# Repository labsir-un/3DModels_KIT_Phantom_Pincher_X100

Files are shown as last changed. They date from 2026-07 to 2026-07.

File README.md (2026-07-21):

# 3DModels — KIT Phantom Pincher X100

Modelos 3D, documentación y archivos de diseño (Autodesk Inventor) del KIT Phantom Pincher X100, un kit de clasificación de objetos basado en el manipulador PhantomX Pincher.

## Ensamble

El ensamble completo (Autodesk Inventor) se encuentra en [`Kit/ensamblesKit/kitDetallado.iam`](Kit/ensamblesKit/kitDetallado.iam).

## Vista general del kit

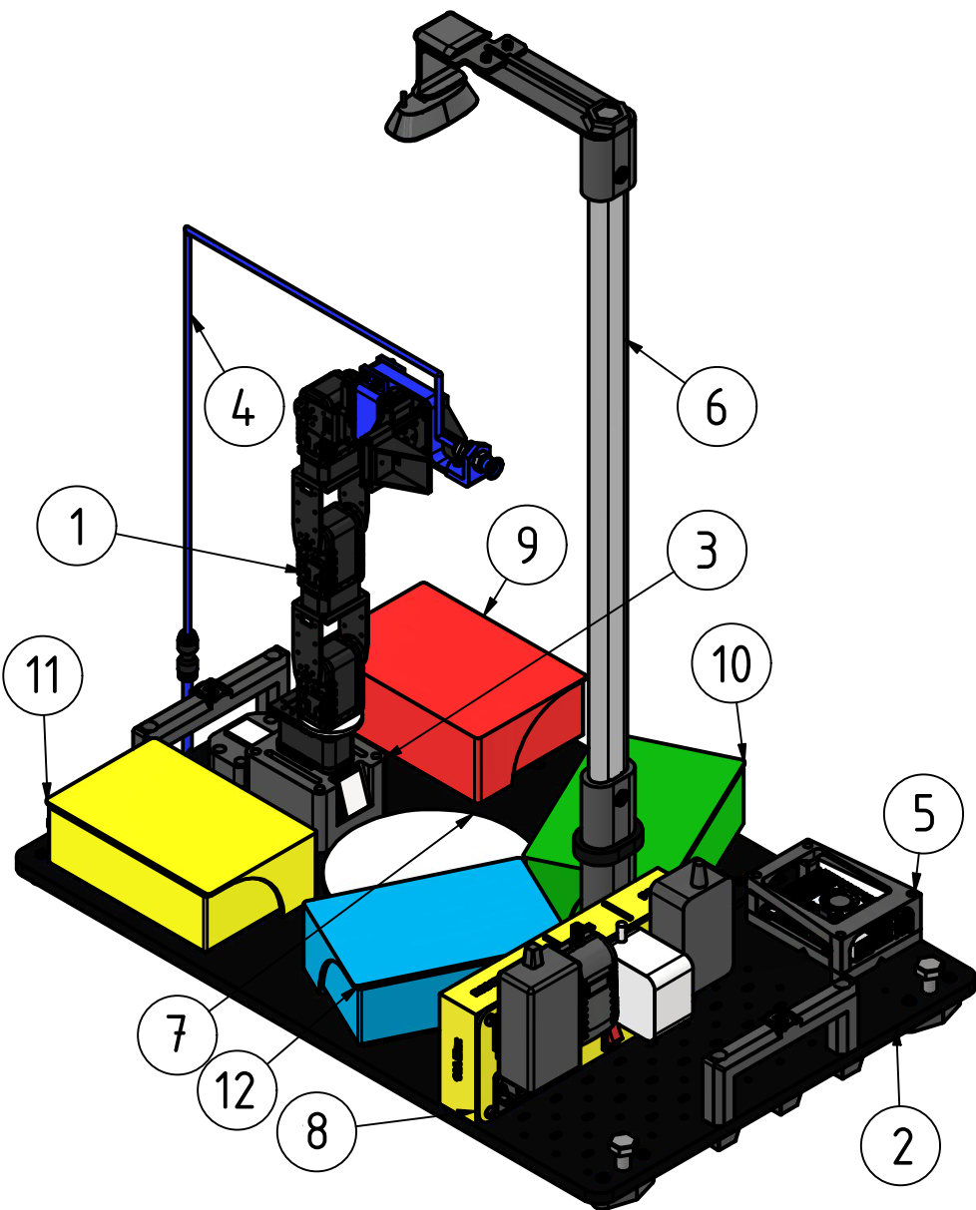
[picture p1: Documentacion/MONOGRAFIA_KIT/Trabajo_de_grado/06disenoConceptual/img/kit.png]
Vista general del kit


Kit de clasificación completo ensamblado. Sus partes son:

1. Manipulador robótico PhantomX Pincher AX-12 con 4 grados de libertad. Carpeta [`Kit/arm/`](Kit/arm), ver [`ensambleBrazo.iam`](Kit/arm/ensambleBrazo.iam).
2. Plataforma base de MDF (554 mm × 360 mm × 9 mm) con acabado negro mate. Carpeta [`Kit/basesParaLosKits/`](Kit/basesParaLosKits), ver [`ensambleBase.iam`](Kit/basesParaLosKits/ensambleBase.iam).
3. Base del manipulador con sistema de identificación numérica. Carpeta [`Kit/arm/`](Kit/arm), ver [`ensambleBaseBrazo.iam`](Kit/arm/ensambleBaseBrazo.iam).
4. Sistema de succión por vacío con gripper intercambiable. Carpeta [`Kit/cases/caseMicroAirPump370A/`](Kit/cases/caseMicroAirPump370A), ver [`ensambleAirpump.iam`](Kit/cases/caseMicroAirPump370A/ensambleAirpump.iam).
5. Controlador Raspberry Pi 5 en carcasa protectora. Carpeta [`Kit/cases/caseRaspberryPi5/turtleCasePi5/`](Kit/cases/caseRaspberryPi5/turtleCasePi5), ver [`raspberryPi5WithCase.iam`](Kit/cases/caseRaspberryPi5/turtleCasePi5/raspberryPi5WithCase.iam).
6. Soporte de cámara con mástil vertical y brazo en voladizo. Carpeta [`Kit/tubosOvaladosNiquel/soporteCamara/`](Kit/tubosOvaladosNiquel/soporteCamara), ver [`ensambleSoporteC270Webcam.iam`](Kit/tubosOvaladosNiquel/soporteCamara/ensambleSoporteC270Webcam.iam).
7. Zona de recolección circular blanca (Ø146 mm). Carpeta [`Kit/zonasDeRecolección/zonaCircular/`](Kit/zonasDeRecolecci%C3%B3n/zonaCircular), ver [`ensambleZonaRecoleccion.iam`](Kit/zonasDeRecolecci%C3%B3n/zonaCircular/ensambleZonaRecoleccion.iam).
8. Multitoma personalizada con control individual de subsistemas. Carpeta [`Kit/cases/multitoma/`](Kit/cases/multitoma), ver [`ensambleMultitoma.iam`](Kit/cases/multitoma/ensambleMultitoma.iam).
9. Caneca de depósito roja. Carpeta [`Kit/Canecas/canecaGrandeConTapaSlide/`](Kit/Canecas/canecaGrandeConTapaSlide), ver [`ensambleCanecaTapaSlide.iam`](Kit/Canecas/canecaGrandeConTapaSlide/ensambleCanecaTapaSlide.iam).
10. Caneca de depósito verde. Carpeta [`Kit/Canecas/canecaGrandeConTapaSlide/`](Kit/Canecas/canecaGrandeConTapaSlide), ver [`ensambleCanecaTapaSlide.iam`](Kit/Canecas/canecaGrandeConTapaSlide/ensambleCanecaTapaSlide.iam).
11. Caneca de depósito azul. Carpeta [`Kit/Canecas/canecaGrandeConTapaSlide/`](Kit/Canecas/canecaGrandeConTapaSlide), ver [`ensambleCanecaTapaSlide.iam`](Kit/Canecas/canecaGrandeConTapaSlide/ensambleCanecaTapaSlide.iam).
12. Caneca de depósito amarilla. Carpeta [`Kit/Canecas/canecaGrandeConTapaSlide/`](Kit/Canecas/canecaGrandeConTapaSlide), ver [`ensambleCanecaTapaSlide.iam`](Kit/Canecas/canecaGrandeConTapaSlide/ensambleCanecaTapaSlide.iam).

Todos los componentes se integran en un contenedor plástico de 600 mm × 400 mm para almacenamiento y transporte.

## Documentación del kit

Toda la información sobre el desarrollo del kit (imágenes del layout, partes, composición del robot, etc.) está en la carpeta [`Documentacion/MONOGRAFIA_KIT`](Documentacion/MONOGRAFIA_KIT). Allí encontrarás:

- [`Monografia_KIT.pdf`](Documentacion/MONOGRAFIA_KIT/Monografia_KIT.pdf): el documento final en PDF.
- [`Trabajo_de_grado/`](Documentacion/MONOGRAFIA_KIT/Trabajo_de_grado): el código fuente en LaTeX junto con las imágenes empleadas para generar el PDF.

## Layout del kit

Las imágenes del layout están en [`06disenoConceptual/img/plataforma/`](Documentacion/MONOGRAFIA_KIT/Trabajo_de_grado/06disenoConceptual/img/plataforma). La versión de referencia es [`layout2.png`](Documentacion/MONOGRAFIA_KIT/Trabajo_de_grado/06disenoConceptual/img/plataforma/layout2.png):

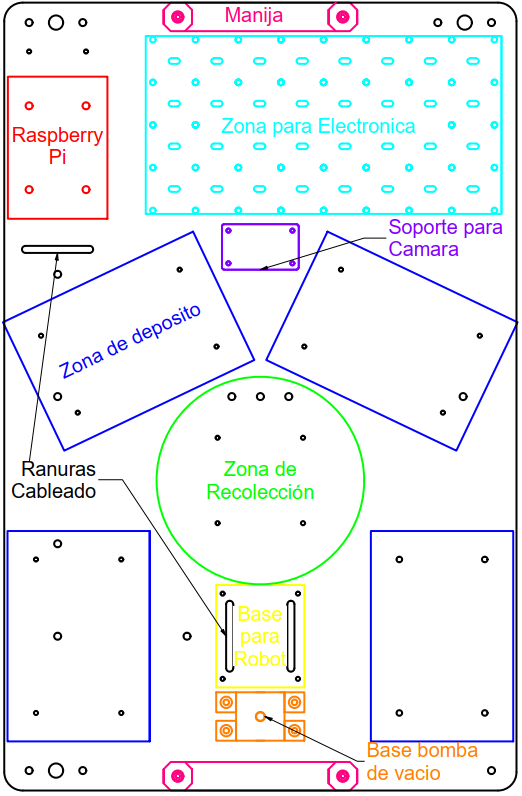
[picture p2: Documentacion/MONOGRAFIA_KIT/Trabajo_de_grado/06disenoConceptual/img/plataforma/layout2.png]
Layout del kit


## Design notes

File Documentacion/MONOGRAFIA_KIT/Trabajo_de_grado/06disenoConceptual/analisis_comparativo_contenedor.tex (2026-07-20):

\subsubsection{Análisis Comparativo de Alternativas}

Para determinar la opción más adecuada de contenedor, se realizó un análisis comparativo detallado considerando aspectos técnicos, económicos y operativos de ambas alternativas.

\paragraph{Especificaciones del Contenedor Comercial Seleccionado}

Se identificó en el mercado nacional una canastilla plástica industrial con las siguientes características:

\begin{itemize}
    \item \textbf{Tipo}: Canastilla plástica 3/4 toda sellada de fábrica
    \item \textbf{Material}: Polipropileno industrial
    \item \textbf{Incluye}: Tapa
    \item \textbf{Capacidad de carga}: 200 kg
    \item \textbf{Costo unitario}: \$25,000 COP
    \item \textbf{Estado}: Nuevo, sellado de fábrica
\end{itemize}

Esta solución comercial fue comparada con la alternativa de fabricación propia mediante un análisis multicriterio.

\paragraph{Análisis de Costos}

La Tabla \ref{tab:costos_contenedor} presenta una comparación detallada de los costos asociados a cada alternativa para la fabricación de los 7 contenedores requeridos.

\begin{table}[H]
\centering
\caption{Comparación de costos entre alternativas de contenedor}
\label{tab:costos_contenedor}
\begin{tabular}{|l|r|r|}
\hline
\textbf{Concepto} & \textbf{Fabricación Propia} & \textbf{Contenedor Comercial} \\
\hline
\hline
\multicolumn{3}{|l|}{\textit{Materiales}} \\
\hline
Madera/MDF (láminas) & \$280,000 & --- \\
Herrajes y bisagras & \$105,000 & --- \\
Asas de transporte & \$42,000 & Incluidas \\
Tornillería & \$21,000 & --- \\
Adhesivos y sellantes & \$35,000 & --- \\
Pintura y acabados & \$70,000 & --- \\
Canastillas plásticas (7 unidades) & --- & \$175,000 \\
\hline
\textbf{Subtotal materiales} & \$553,000 & \$175,000 \\
\hline
\hline
\multicolumn{3}{|l|}{\textit{Procesos y mano de obra}} \\
\hline
Corte de materiales & \$140,000 & --- \\
Ensamblaje & \$210,000 & --- \\
Acabado superficial & \$105,000 & --- \\
\hline
\textbf{Subtotal procesos} & \$455,000 & \$0 \\
\hline
\hline
\multicolumn{3}{|l|}{\textit{Herramientas y equipos}} \\
\hline
Arriendo/depreciación herramientas & \$84,000 & --- \\
\hline
\textbf{Subtotal herramientas} & \$84,000 & \$0 \\
\hline
\hline
\textbf{COSTO TOTAL (7 unidades)} & \$1,092,000 & \$175,000 \\
\textbf{Costo unitario} & \$156,000 & \$25,000 \\
\hline
\end{tabular}
\end{table}

El análisis de costos revela una diferencia significativa de \$917,000 COP a favor de la opción comercial, lo que representa un ahorro del 84\% respecto a la fabricación propia.

\paragraph{Análisis de Tiempos}

La Tabla \ref{tab:tiempos_contenedor} compara los tiempos de implementación requeridos para cada alternativa.

\begin{table}[H]
\centering
\caption{Comparación de tiempos de implementación}
\label{tab:tiempos_contenedor}
\begin{tabular}{|l|r|r|}
\hline
\textbf{Actividad} & \textbf{Fabricación Propia} & \textbf{Contenedor Comercial} \\
\hline
Diseño detallado & 16 horas & 0 horas \\
Adquisición de materiales & 8 horas & 2 horas \\
Fabricación/corte & 24 horas & --- \\
Ensamblaje & 28 horas & --- \\
Acabados & 16 horas & --- \\
Curado y secado & 48 horas & --- \\
Inspección y ajustes & 8 horas & 1 hora \\
\hline
\textbf{TOTAL} & \textbf{148 horas} & \textbf{3 horas} \\
\textbf{Días laborales (8h/día)} & \textbf{18.5 días} & \textbf{0.4 días} \\
\hline
\end{tabular}
\end{table}

La opción comercial representa un ahorro de 145 horas de trabajo, equivalente a aproximadamente 18 días laborales, permitiendo dedicar este tiempo a otras actividades críticas del proyecto.

\paragraph{Análisis Técnico Comparativo}

La Tabla \ref{tab:comparativo_tecnico} presenta una evaluación de los aspectos técnicos y funcionales de ambas alternativas.

\begin{table}[H]
\centering
\caption{Análisis técnico comparativo de alternativas de contenedor}
\label{tab:comparativo_tecnico}
\small
\begin{tabular}{|p{4cm}|p{5cm}|p{5cm}|}
\hline
\textbf{Criterio} & \textbf{Fabricación Propia} & \textbf{Contenedor Comercial} \\
\hline
\hline
\textbf{Capacidad de carga} & 150-180 kg (estimado, requiere refuerzos) & 200 kg (certificado) \\
\hline
\textbf{Resistencia a apilamiento} & Variable, depende de la construcción & Certificada para apilamiento industrial \\
\hline
\textbf{Resistencia a humedad} & Requiere sellado y mantenimiento periódico & Resistente, material impermeable \\
\hline
\textbf{Durabilidad} & 3-5 años con mantenimiento & 10+ años, sin mantenimiento \\
\hline
\textbf{Peso del contenedor} & 8-12 kg (madera/MDF) & 3-4 kg (plástico) \\
\hline
\textbf{Transportabilidad} & Limitada por peso y volumen & Excelente, liviano con asas integradas \\
\hline
\textbf{Estandarización} & Cada unidad puede variar ligeramente & Todas las unidades idénticas \\
\hline
\textbf{Mantenimiento} & Requiere repintado, ajuste de herrajes & Mínimo, solo limpieza \\
\hline
\textbf{Reemplazo} & Difícil, requiere fabricación nueva & Inmediato, disponible en mercado \\
\hline
\textbf{Personalización} & Alta, diseño completamente adaptable & Limitada a dimensiones estándar \\
\hline
\textbf{Estética} & Profesional con buen acabado & Industrial, funcional \\
\hline
\end{tabular}
\end{table}

\paragraph{Matriz de Decisión}

Para la selección final se empleó una matriz de decisión multicriterio ponderada (Tabla \ref{tab:matriz_decision}), asignando pesos a cada criterio según su importancia relativa en el contexto del proyecto.

\begin{table}[H]
\centering
\caption{Matriz de decisión multicriterio para selección de contenedor}
\label{tab:matriz_decision}
\begin{tabular}{|l|c|c|c|c|c|}
\hline
\textbf{Criterio} & \textbf{Peso} & \multicolumn{2}{c|}{\textbf{Fabricación Propia}} & \multicolumn{2}{c|}{\textbf{Contenedor Comercial}} \\
\cline{3-6}
 & (\%) & Calif. & Pond. & Calif. & Pond. \\
\hline
Costo & 25 & 4 & 1.00 & 10 & 2.50 \\
Tiempo de implementación & 20 & 3 & 0.60 & 10 & 2.00 \\
Capacidad de carga & 15 & 7 & 1.05 & 9 & 1.35 \\
Durabilidad & 15 & 6 & 0.90 & 9 & 1.35 \\
Facilidad de transporte & 10 & 5 & 0.50 & 9 & 0.90 \\
Disponibilidad & 10 & 4 & 0.40 & 10 & 1.00 \\
Mantenimiento & 5 & 5 & 0.25 & 10 & 0.50 \\
\hline
\textbf{TOTAL} & \textbf{100} & --- & \textbf{4.70} & --- & \textbf{9.60} \\
\hline
\end{tabular}
\end{table}

\textit{Nota: Calificación en escala de 1 a 10, donde 10 es el mejor desempeño.}

\paragraph{Conclusión del Análisis}

El análisis comparativo multicriterio demostró que la opción de contenedor comercial (canastilla plástica industrial) es significativamente superior a la fabricación propia, obteniendo una puntuación ponderada de 9.60 frente a 4.70.

Las ventajas decisivas del contenedor comercial son:

\begin{enumerate}
    \item \textbf{Ventaja económica}: Ahorro de \$917,000 COP (84\%) en el costo total de los 7 contenedores
    \item \textbf{Ventaja temporal}: Reducción de 18 días laborales en el tiempo de implementación
    \item \textbf{Ventaja técnica}: Capacidad de carga certificada de 200 kg, superior a la estimada para fabricación propia
    \item \textbf{Ventaja operativa}: Menor peso (3-4 kg vs 8-12 kg), facilitando el transporte manual
    \item \textbf{Ventaja de mantenimiento}: Material resistente a humedad sin requerimiento de mantenimiento periódico
    \item \textbf{Ventaja de disponibilidad}: Reemplazo inmediato en caso de daño o necesidad de unidades adicionales
\end{enumerate}

La única ventaja de la fabricación propia sería la personalización completa del diseño; sin embargo, esta ventaja no compensa las múltiples desventajas en costo, tiempo, y características técnicas.

Por estas razones, se seleccionó la canastilla plástica industrial como contenedor definitivo para los 7 kits del proyecto, permitiendo una implementación más rápida, económica y técnicamente superior, liberando recursos financieros y temporales que pueden ser destinados a otros componentes críticos del kit de clasificación.

    \begin{figure}[H]
        \centering
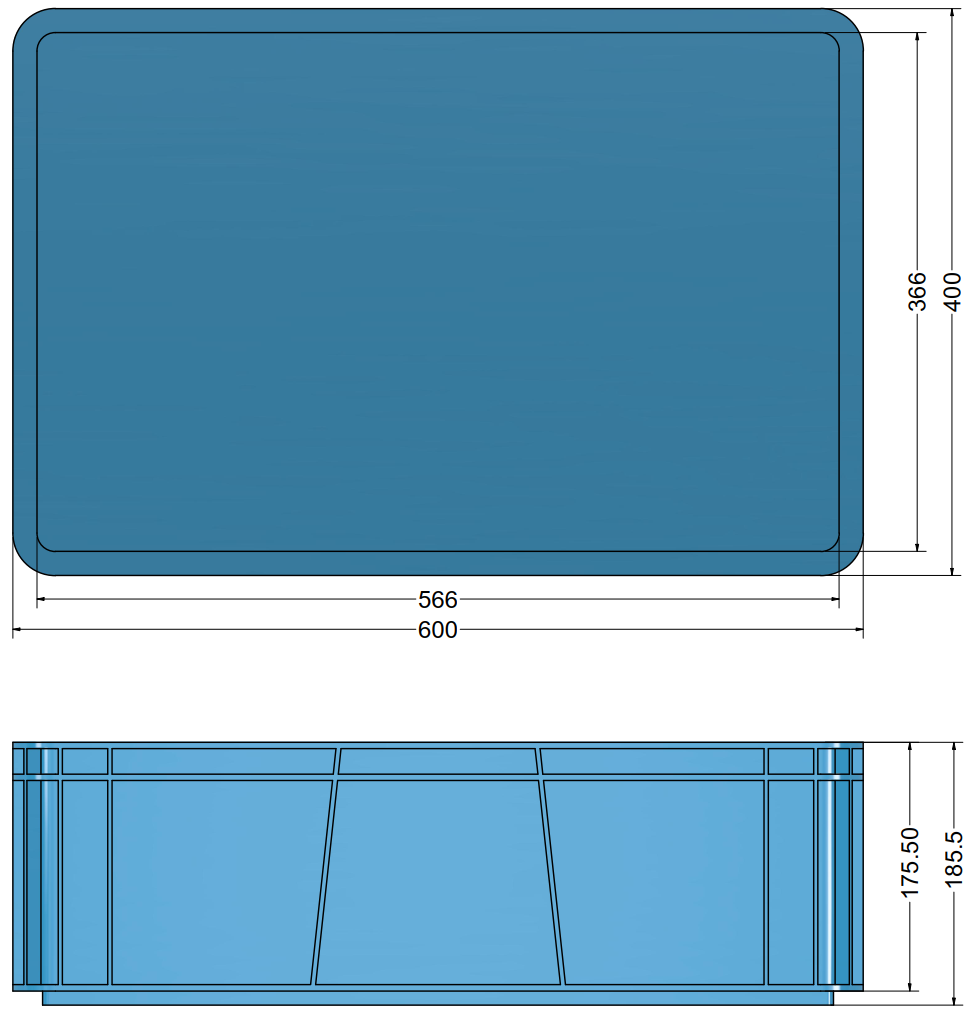
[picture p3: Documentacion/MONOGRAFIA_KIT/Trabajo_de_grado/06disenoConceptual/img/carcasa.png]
        
        \caption{Vista superior y lateral de canastilla 3/4 sellada con dimensiones externas e internas.}
        \label{fig:carcasa}
    \end{figure}

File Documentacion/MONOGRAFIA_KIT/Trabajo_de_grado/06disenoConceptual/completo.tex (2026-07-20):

\section{Kit de Clasificación Completo}

La integración de todos los subsistemas diseñados (mecánico, neumático, de control, de visión y eléctrico) resulta en un kit educativo compacto y funcional para enseñanza de robótica, visión por computador y ROS2. La Figura \ref{fig:kitCompleto} presenta el ensamblaje completo del kit con todos sus componentes principales.

\begin{figure}[H]
    \centering
    
    \caption{Kit de clasificación completo ensamblado. (1) Manipulador robótico PhantomX Pincher AX-12 con 4 grados de libertad, (2) Plataforma base de MDF (554 mm × 360 mm × 9 mm) con acabado negro mate, (3) Base del manipulador con sistema de identificación numérica, (4) Sistema de succión por vacío con gripper intercambiable, (5) Controlador Raspberry Pi 5 en carcasa protectora, (6) Soporte de cámara con mástil vertical y brazo en voladizo, (7) Zona de recolección circular blanca (Ø146 mm), (8) Multitoma personalizada con control individual de subsistemas, (9) Caneca de depósito roja, (10) Caneca de depósito verde, (11) Caneca de depósito azul, (12) Caneca de depósito amarilla. Todos los componentes se integran en contenedor plástico de 600 mm × 400 mm para almacenamiento y transporte.}
    \label{fig:kitCompleto}
\end{figure}

\subsection{Componentes Principales del Kit}

El kit integrado está compuesto por los siguientes subsistemas y componentes principales:

\begin{table}[H]
\centering
\caption{Componentes principales del kit de clasificación}
\label{tab:componentes_kit}
\small
\begin{tabular}{|c|l|}
\hline
\textbf{\#} & \textbf{Componente/Subsistema} \\
\hline
1 & Manipulador PhantomX Pincher AX-12 \\
2 & Plataforma base \\
3 & Base de manipulador \\
4 & Sistema de succión por vacío \\
5 & Controlador (Raspberry Pi 5) \\
6 & Soporte de cámara \\
7 & Zona de recolección \\
8 & Multitoma personalizada \\
9 & Caneca de depósito roja \\
10 & Caneca de depósito verde \\
11 & Caneca de depósito azul \\
12 & Caneca de depósito amarilla \\
\hline
\end{tabular}
\end{table}

\subsection{Características Generales del Kit}

El kit completo presenta las siguientes características técnicas y operativas:

\subsubsection{Dimensiones y Peso}

\begin{itemize}
    \item \textbf{Plataforma operativa}: 554 mm × 360 mm × 706 mm (largo × ancho × alto máximo con soporte de cámara)
    \item \textbf{Contenedor de almacenamiento}: 600 mm × 400 mm × 171 mm (exteriores)
    \item \textbf{Peso total estimado}: 4.5-5.5 kg (incluye todos los componentes y objetos de clasificación)
    \item \textbf{Portabilidad}: Transporte manual mediante asas integradas en contenedor
\end{itemize}

\subsubsection{Capacidades Funcionales}

\begin{itemize}
    \item \textbf{Espacio de trabajo}: Zona de recolección de Ø146 mm más cuatro zonas de depósito
    \item \textbf{Capacidad de manipulación}: Objetos de 25 mm × 25 mm × 25 mm, peso máximo 30 g
    \item \textbf{Tipos de objetos}: 4 geometrías distinguibles (cuadrado, rectángulo, círculo, pentágono)
    \item \textbf{Modos de operación}: Gripper mecánico o sistema de succión por vacío (intercambiables)
    \item \textbf{Clasificación por color}: 4 categorías (rojo, verde, azul, amarillo)
\end{itemize}

\subsubsection{Subsistemas Integrados}

\begin{itemize}
    \item \textbf{Subsistema mecánico}: Manipulador de 4 DOF, plataforma estructural, zonas de trabajo
    \item \textbf{Subsistema neumático}: Bomba de vacío 370A, ventosa PAK-15, mangueras de 4-6 mm
    \item \textbf{Subsistema de control}: Raspberry Pi 5 (8 GB RAM), Ubuntu 24.04 LTS, ROS2 Jazzy
    \item \textbf{Subsistema de visión}: Cámara Logitech C270, soporte ajustable en altura
    \item \textbf{Subsistema eléctrico}: Multitoma con 4 salidas, 3 switches individuales, protección por fusible 15A
\end{itemize}

\subsubsection{Recursos Didácticos}

El kit proporciona plataforma para práctica de:

\begin{itemize}
    \item Cinemática directa e inversa de manipuladores seriales
    \item Control de servomotores Dynamixel mediante protocolos de comunicación
    \item Visión por computador (segmentación de color, detección de formas, calibración de cámara)
    \item Programación de nodos ROS2 en Python/C++
    \item Planificación de trayectorias y evasión de colisiones
    \item Integración de sensores y actuadores en sistemas robóticos
    \item Desarrollo de interfaces de usuario para control de robots
\end{itemize}

\subsection{Configuración de Almacenamiento}

Todos los componentes del kit se almacenan en el contenedor plástico sellado mediante la siguiente distribución:

\begin{itemize}
    \item \textbf{Nivel inferior}: Plataforma base con canecas, zona de recolección, multitoma y base de manipulador fijos
    \item \textbf{Nivel medio}: Manipulador desmontado, carcasa de Raspberry Pi, bomba de vacío
    \item \textbf{Nivel superior}: Mástil de soporte de cámara (diagonal), gripper de succión, objetos de clasificación, cableado
    \item \textbf{Compartimentos laterales}: Fuentes de alimentación, cable de poder, mangueras neumáticas
\end{itemize}

Las tapas deslizantes de las canecas se cierran durante almacenamiento, conteniendo objetos de clasificación y previendo su pérdida durante transporte.

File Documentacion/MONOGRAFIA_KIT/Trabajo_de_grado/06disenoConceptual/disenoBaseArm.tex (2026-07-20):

\subsection{Diseño de la Base del Manipulador}

La base del manipulador constituye la interfaz mecánica entre el robot PhantomX Pincher y la plataforma del kit. Su diseño se fundamentó en la preservación de características funcionales de la base original, incorporando mejoras estructurales y adaptaciones específicas para el nuevo sistema.

\subsubsection{Análisis de la Base Original}

La base original del robot PhantomX Pincher AX-12 (Figura \ref{fig:ensambleOldBaseArm}) sirvió como referencia para el diseño, proporcionando información valiosa sobre dimensiones, sistemas de fijación y requisitos operativos.

\begin{figure}[H]
    \centering
    
    \caption{Base original del robot PhantomX Pincher AX-12. (1) Base superior de acrílico que soporta el servomotor principal, (2) Base inferior de acrílico para fijación a superficies, (3) Cuatro espaciadores hexagonales de nylon M3, (4) Manipulador PhantomX Pincher. Se observan las ranuras laterales para paso de cableado.}
    \label{fig:ensambleOldBaseArm}
\end{figure}

\begin{table}[H]
\centering
\caption{Componentes de la base original del PhantomX Pincher AX-12}
\label{tab:base_original}
\small
\begin{tabular}{|c|l|c|l|}
\hline
\textbf{\#} & \textbf{Componente} & \textbf{Cant.} & \textbf{Material} \\
\hline
1 & Base superior de manipulador & 1 & Acrílico \\
2 & Base inferior de manipulador & 1 & Acrílico \\
3 & Espaciador hexagonal de nylon M3 & 4 & Nylon \\
4 & Manipulador & 1 & --- \\
\hline
\end{tabular}
\end{table}

La altura de la base original es de 48 mm (Figura \ref{fig:medidaBaseArmOld}), dimensión que se conservó en el diseño final para mantener la compatibilidad cinemática con los algoritmos de control existentes.

\begin{figure}[H]
    \centering
    
    \caption{Vista lateral de la base original mostrando la altura total de 48 mm desde la superficie de montaje hasta la interfaz del manipulador.}
    \label{fig:medidaBaseArmOld}
\end{figure}

\subsubsection{Características Preservadas del Diseño Original}

Del diseño original se conservaron los siguientes elementos funcionales:

\begin{itemize}
    \item \textbf{Sistema de espaciadores hexagonales}: Se mantiene el uso de cuatro espaciadores M3 para fijación del manipulador, garantizando compatibilidad mecánica
    \item \textbf{Ranuras laterales de cableado}: Se preservan las dos aberturas laterales que permiten el paso de cables desde la zona de electrónica hasta el manipulador
    \item \textbf{Altura estándar}: Se conserva la altura de 48 mm para mantener la compatibilidad con la cinemática del robot
\end{itemize}

\subsubsection{Modificaciones e Innovaciones del Diseño}

El diseño final incorpora mejoras significativas respecto a la base original:

\paragraph{Eliminación de la Base Inferior}

Se suprimió la placa inferior de la base original, ya que la plataforma del kit cumple esta función. Esta simplificación reduce:
\begin{itemize}
    \item Número de componentes del sistema
    \item Costo de fabricación
    \item Peso total del conjunto
    \item Complejidad de ensamblaje
\end{itemize}

\paragraph{Integración con Sistema de Vacío}

Se diseñó una cavidad semicircular en la parte posterior de la base (visible en la Figura \ref{fig:medidasBaseArm}) para alojar la bomba de vacío. Esta integración permite:
\begin{itemize}
    \item Aprovechamiento óptimo del espacio disponible
    \item Proximidad entre bomba de vacío y manipulador, minimizando longitud de mangueras
    \item Protección parcial de la bomba dentro del volumen de la base
\end{itemize}

\begin{figure}[H]
    \centering
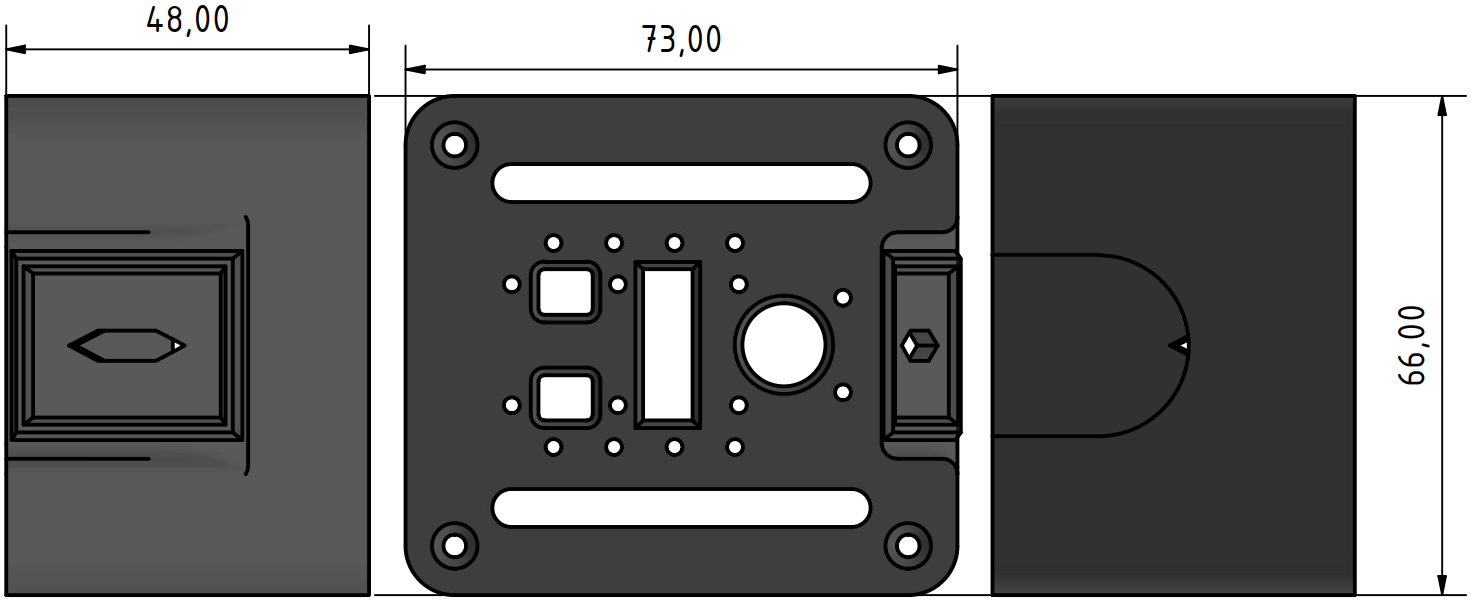
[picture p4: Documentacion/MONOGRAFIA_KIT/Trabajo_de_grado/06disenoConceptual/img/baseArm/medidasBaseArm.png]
    
    \caption{Vista superior de la base del manipulador con dimensiones principales. Dimensiones exteriores: 73 mm × 66 mm. Se observan: cavidad semicircular posterior de 48 mm de diámetro para alojamiento de bomba de vacío, ranuras laterales de cableado, patrón de montaje para espaciadores hexagonales M3, y diversas perforaciones para paso de cables y ventilación.}
    \label{fig:medidasBaseArm}
\end{figure}

\paragraph{Sistema de Identificación}

Dado que se fabricarán siete kits completos, se incorporó un sistema de identificación mediante una placa plástica intercambiable montada en el frente de la base. Esta ubicación frontal fue seleccionada por:
\begin{itemize}
    \item Alta visibilidad desde cualquier ángulo de aproximación al kit
    \item Facilidad de lectura para usuarios y personal de laboratorio
    \item Posibilidad de reemplazo sin desmontar el manipulador
\end{itemize}

\paragraph{Mejora del Material de Espaciadores}

Se sustituyeron los espaciadores hexagonales de nylon por espaciadores de latón M3 × 30 mm. Esta modificación se fundamentó en la experiencia operativa: durante el desmontaje del manipulador de su base original, varios espaciadores de nylon se fracturaron. El latón ofrece:
\begin{itemize}
    \item Mayor resistencia mecánica a cargas de tracción y compresión
    \item Durabilidad superior frente a ciclos repetidos de montaje/desmontaje
    \item Roscas más resistentes al desgaste
    \item Mejor tolerancia dimensional
\end{itemize}

\paragraph{Soporte Estructural Mejorado}

A diferencia de la base original que se apoyaba únicamente en cuatro puntos (los espaciadores), el diseño final apoya todo su perímetro sobre la plataforma base. Esta configuración proporciona:
\begin{itemize}
    \item Mayor rigidez estructural del conjunto
    \item Distribución más uniforme de cargas operativas
    \item Reducción de vibraciones durante movimientos del manipulador
    \item Estabilidad mejorada para operaciones de alta precisión
\end{itemize}

\subsubsection{Restricciones Dimensionales}

Las dimensiones en planta de la base (73 mm × 66 mm) se determinaron considerando las restricciones espaciales impuestas por el layout de la plataforma (Figura \ref{fig:layout2}). Específicamente, el área ocupada por la base no debe interferir con el cierre de las tapas deslizantes de las canecas adyacentes. Un incremento dimensional de la base invadiría la trayectoria de las tapas, impidiendo el cierre completo de las zonas de depósito.

\subsubsection{Ensamble del Conjunto}

El conjunto completo de la base del manipulador se presenta en la Figura \ref{fig:ensambleBaseArm}.

\begin{figure}[H]
    \centering
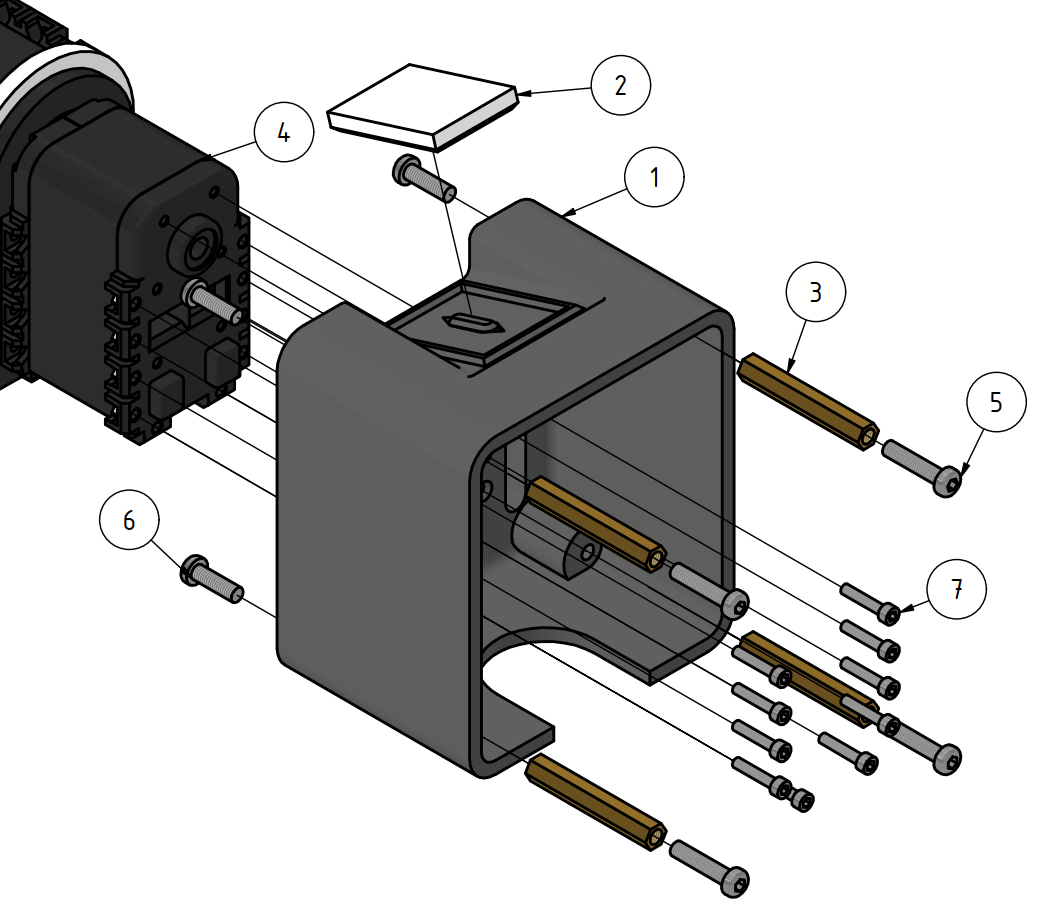
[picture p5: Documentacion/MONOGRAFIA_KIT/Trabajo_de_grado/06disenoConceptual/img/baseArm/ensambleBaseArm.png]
    
    \caption{Ensamble explosionado de la base del manipulador. (1) Cuerpo de la base fabricado mediante FDM, (2) Placa de identificación numérica intercambiable, (3) Cuatro espaciadores hexagonales de latón M3 × 30 mm, (4) Manipulador PhantomX Pincher, (5) Tornillos M3 × 14 mm para fijación de espaciadores a la base, (6) Tornillos M3 × 10 mm para fijación de la placa identificadora, (7) Tornillos M2 × 10 mm (10 unidades) para fijación del manipulador a los espaciadores.}
    \label{fig:ensambleBaseArm}
\end{figure}

\begin{table}[H]
\centering
\caption{Lista de materiales de la base del manipulador}
\label{tab:bom_base_manipulador}
\small
\begin{tabular}{|c|l|c|l|l|}
\hline
\textbf{\#} & \textbf{Componente} & \textbf{Cant.} & \textbf{Fabricación} & \textbf{Material} \\
\hline
1 & Base de manipulador & 1 & FDM & ABS/PLA \\
2 & Placa de número identificador & 1 & FDM & ABS/PLA \\
3 & Espaciador hexagonal M3 × 30 mm & 4 & Comercial & Latón \\
4 & Manipulador & 1 & --- & --- \\
5 & Tornillo M3 × 14 mm & 4 & Comercial & Acero \\
6 & Tornillo M3 × 10 mm & 4 & Comercial & Acero \\
7 & Tornillo M2 × 10 mm & 10 & Comercial & Acero \\
\hline
\end{tabular}
\end{table}

Los espaciadores hexagonales se fijan a la base mediante tornillos M3 × 14 mm que se enroscan directamente en el latón. El manipulador se monta sobre estos espaciadores utilizando los tornillos M2 × 10 mm originales del robot, reutilizando componentes existentes y reduciendo costos.

El diseño final de la base del manipulador representa una evolución optimizada del concepto original, integrando mejoras estructurales, consideraciones de manufactura, y requisitos específicos del sistema completo del kit educativo.

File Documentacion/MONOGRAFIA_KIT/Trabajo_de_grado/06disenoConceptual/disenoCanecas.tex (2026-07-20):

\subsection{Diseño de Zonas de Depósito}

Las zonas de depósito constituyen los receptáculos donde el manipulador deposita los objetos clasificados. El diseño de estos componentes evolucionó a través de un proceso iterativo que permitió identificar y resolver múltiples deficiencias del concepto inicial.

\subsubsection{Primera Iteración: Canecas con Sistema de Imanes}

El diseño inicial contemplaba dos tipos de canecas de diferentes tamaños (Figura \ref{fig:canecasIman}): canecas grandes para objetos voluminosos y canecas pequeñas para objetos de menor tamaño. Ambos tipos incorporaban imanes de neodimio en su base para acoplarse a los módulos cuadrados y rectangulares de la primera iteración de la plataforma base.

\begin{figure}[H]
    \centering
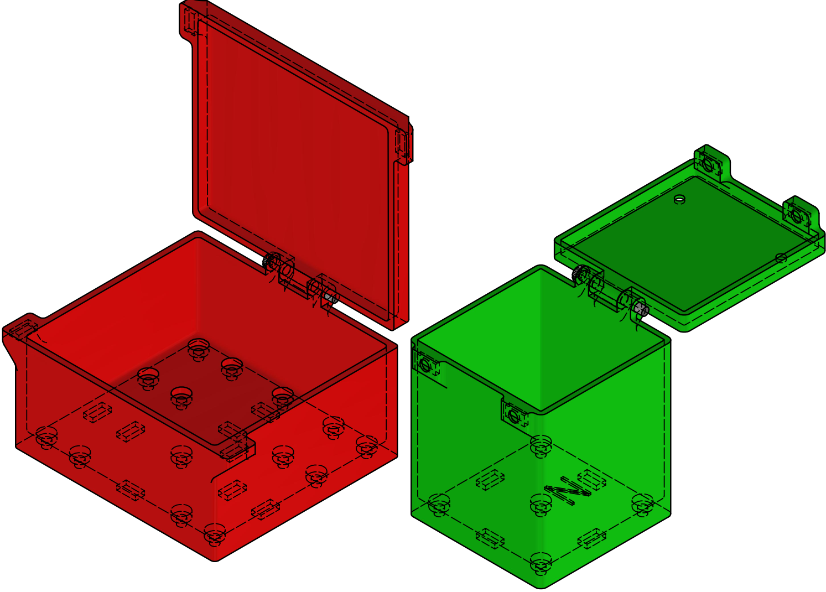
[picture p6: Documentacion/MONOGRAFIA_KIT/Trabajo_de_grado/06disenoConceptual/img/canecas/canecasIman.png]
    
    \caption{Primera iteración del diseño de zonas de depósito. Se muestran dos tipos de canecas (grande en rojo y pequeña en verde) equipadas con imanes de neodimio en su base y tapas abatibles por bisagra. Ambos diseños incluyen cavidades para alojar imanes y agujeros roscados para fijación opcional a la plataforma.}
    \label{fig:canecasIman}
\end{figure}

Estas canecas incluían tapas con bisagra y agujeros para anclaje permanente opcional a la plataforma. Sin embargo, este diseño fue descartado completamente debido a las siguientes deficiencias críticas:

\begin{enumerate}
    \item \textbf{Dependencia de imanes}: El sistema de fijación basado en atracción magnética resultó insuficientemente robusto para garantizar estabilidad durante las operaciones de depósito y transporte
    
    \item \textbf{Interferencia visual}: Los agujeros de tornillería visibles en la superficie superior comprometían los algoritmos de visión por computador, dificultando la discriminación entre objetos de interés y elementos estructurales (cabezas de tornillos)
    
    \item \textbf{Restricción de accesibilidad}: Las dimensiones de apertura no permitían la entrada de la garra del robot, limitando la funcionalidad exclusivamente a depósito y eliminando la posibilidad de recolección desde las canecas
    
    \item \textbf{Complejidad innecesaria}: El diseño requería múltiples tipos de elementos de fijación (tornillos, tuercas, imanes) aumentando costo y dificultad de ensamblaje
    
    \item \textbf{Aprovechamiento ineficiente del espacio}: El mecanismo de cierre por bisagra generaba volumen muerto en la parte superior de las canecas
\end{enumerate}

\subsubsection{Especificación de Requerimientos para el Rediseño}

A partir de las deficiencias identificadas, se establecieron los siguientes requerimientos para las iteraciones subsecuentes:

\begin{itemize}
    \item La garra del PhantomX Pincher debe poder acceder al interior de las canecas, tanto para depósito como para eventual recolección de objetos
    \item Geometría simple sin artefactos visuales que puedan interferir con los algoritmos de visión por computador
    \item Reducción del número de componentes y simplificación del ensamblaje
    \item Estandarización en un único tipo de caneca para todas las zonas de depósito
    \item Sistema de fijación permanente a la plataforma base
    \item Conservación de sistema de cierre para contención de objetos durante transporte
\end{itemize}

\subsubsection{Análisis Dimensional para Accesibilidad de Garras}

El dimensionamiento de las canecas consideró la compatibilidad con dos variantes del robot PhantomX Pincher disponibles en el laboratorio:

\paragraph{PhantomX Pincher AX-12}
La garra de esta variante (Figura \ref{fig:garraPXP-AX12}) presenta dimensiones de aproximadamente 72 mm de ancho por 61 mm de alto.

\begin{figure}[H]
    \centering
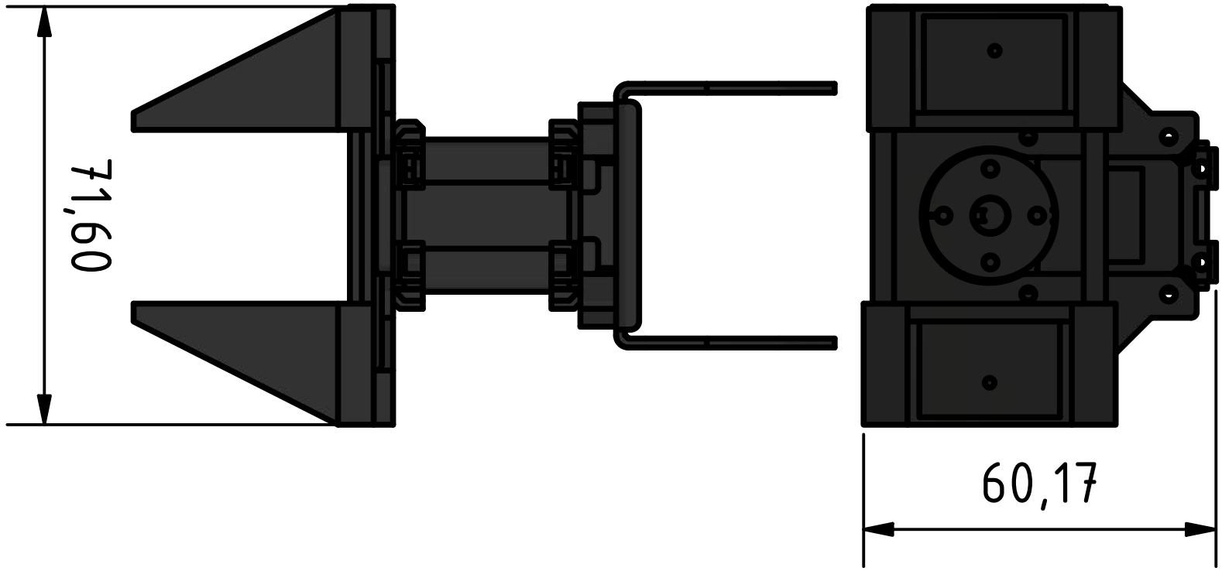
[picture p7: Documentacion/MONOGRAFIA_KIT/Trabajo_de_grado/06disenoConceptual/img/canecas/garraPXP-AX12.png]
    
    \caption{Garra del robot PhantomX Pincher AX-12. Dimensiones: 72 mm de ancho × 61 mm de alto. Se observan los dedos de la garra (cian) y el servomotor Dynamixel AX-12A (rosa) que controla la apertura/cierre.}
    \label{fig:garraPXP-AX12}
\end{figure}

\paragraph{PhantomX Pincher A100}
La garra de esta variante (Figura \ref{fig:garraPXA100}) posee dimensiones mayores: 104 mm de ancho por 54 mm de alto aproximadamente.

\begin{figure}[H]
    \centering
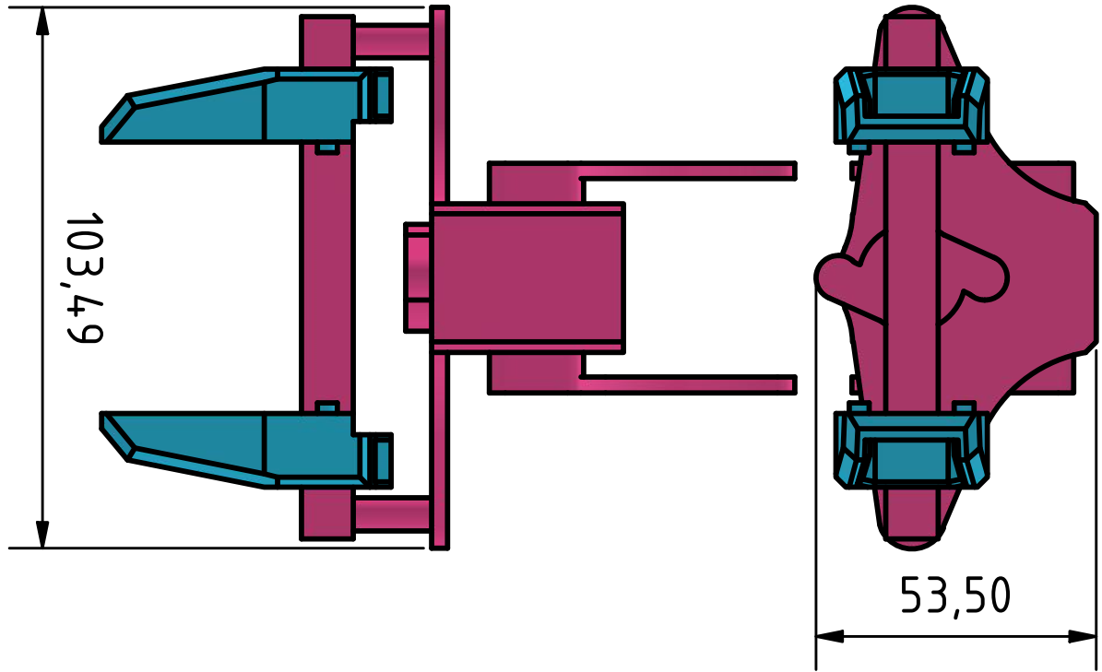
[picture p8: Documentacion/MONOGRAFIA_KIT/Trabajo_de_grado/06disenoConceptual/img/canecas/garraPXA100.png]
    
    \caption{Garra del robot PhantomX Pincher A100. Dimensiones: 104 mm de ancho × 54 mm de alto. Esta variante presenta mayor apertura máxima que el modelo AX-12.}
    \label{fig:garraPXA100}
\end{figure}

\subsubsection{Diseño Final de las Canecas}

El diseño definitivo de las canecas se desarrolló considerando las restricciones cinemáticas, espaciales y de manufactura identificadas durante el proceso de diseño de la plataforma.

\paragraph{Dimensionamiento Longitudinal}

El largo de las canecas se determinó a partir del ángulo de rotación de 58.9° de las zonas de depósito visible en los layouts de las Figuras \ref{fig:layout1} y \ref{fig:layout2}. Partiendo de este ángulo, se maximizó la dimensión longitudinal sin invadir áreas asignadas a otros componentes, resultando en un ancho exterior de 148 mm y un ancho interior útil de 142 mm.

\paragraph{Apertura Frontal}

Se incorporó una apertura frontal de 131 mm de ancho que permite el acceso de la garra por el frente de la caneca. Esta dimensión proporciona holguras laterales de:
\begin{itemize}
    \item 29 mm por lado para la garra AX-12 (ancho 72 mm)
    \item 13 mm por lado para la garra A100 (ancho 104 mm)
\end{itemize}

Estas holguras son suficientes para permitir el ingreso de las garras considerando tolerancias de posicionamiento del manipulador.

\paragraph{Sistema de Tapa Deslizante}

En la parte inferior de la apertura frontal se incorporó un chaflán de 45° que define una guía para una tapa deslizante. Este diseño ofrece ventajas significativas sobre el sistema de bisagra del diseño anterior:

\begin{itemize}
    \item La tapa no puede ser desplazada verticalmente, permaneciendo cautiva durante el transporte
    \item El movimiento únicamente horizontal facilita las operaciones de cierre
    \item Se elimina el volumen muerto superior presente en el diseño con bisagra
\end{itemize}

\begin{figure}[H]
    \centering
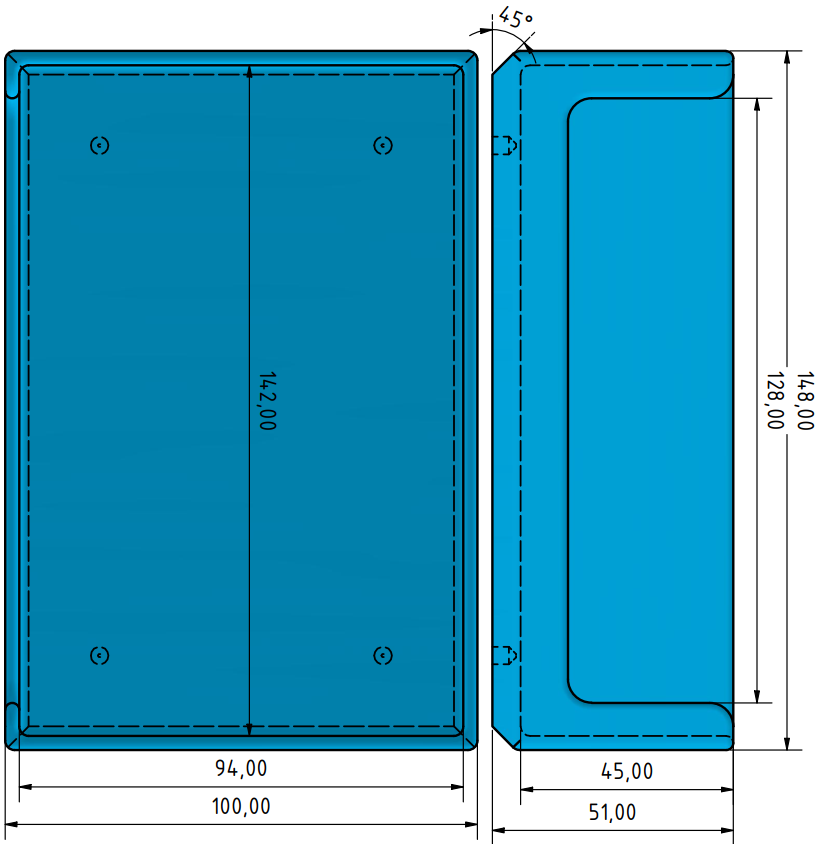
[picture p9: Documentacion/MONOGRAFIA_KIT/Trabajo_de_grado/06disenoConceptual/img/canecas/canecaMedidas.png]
    
    \caption{Vistas ortogonales de la caneca final con dimensiones principales. Vista superior: 100 mm × 94 mm exteriores, interior de 142 mm de profundidad. Vista lateral: altura total de 148 mm (128 mm útiles), profundidad de 51 mm (45 mm útiles). Se observa el chaflán de 45° para la guía de la tapa deslizante y las posiciones de los insertos roscados M3.}
    \label{fig:canecaMedidas}
\end{figure}

\paragraph{Sistema de Fijación con Insertos Térmicos}

Se implementó un sistema de fijación mediante cuatro insertos roscados M3 para plástico ubicados en la base de la caneca. Estos insertos se instalan mediante inserción térmica: se calientan y se introducen en cavidades cilíndricas diseñadas específicamente, donde el plástico circundante se funde parcialmente y fluye hacia las ranuras del inserto, creando una unión mecánica permanente al enfriarse.

Este sistema ofrece múltiples ventajas:
\begin{itemize}
    \item Los tornillos M3 que fijan la caneca a la plataforma quedan ocultos en la cara inferior, eliminando elementos visuales en la superficie superior
    \item Las roscas metálicas resisten ciclos repetidos de montaje/desmontaje sin degradación
    \item No se requieren tuercas, simplificando el ensamblaje
    \item La superficie superior de la caneca queda completamente limpia, optimizando el desempeño de los algoritmos de visión por computador
\end{itemize}

\paragraph{Separadores de Altura}

Se incorporaron cuatro separadores entre la plataforma base y la caneca. Estos separadores cumplen dos funciones esenciales:

\begin{enumerate}
    \item Nivelar la altura de las canecas con la zona de recolección, que es una pieza elevada respecto a la plataforma base
    \item Proporcionar el espacio necesario para que la tapa deslizante pueda desplazarse completamente y cerrar la caneca
\end{enumerate}

\paragraph{Ensamble Completo}

El subconjunto completo de la zona de depósito se presenta en la Figura \ref{fig:ensambleCanecaTapaSlide}.

\begin{figure}[H]
    \centering
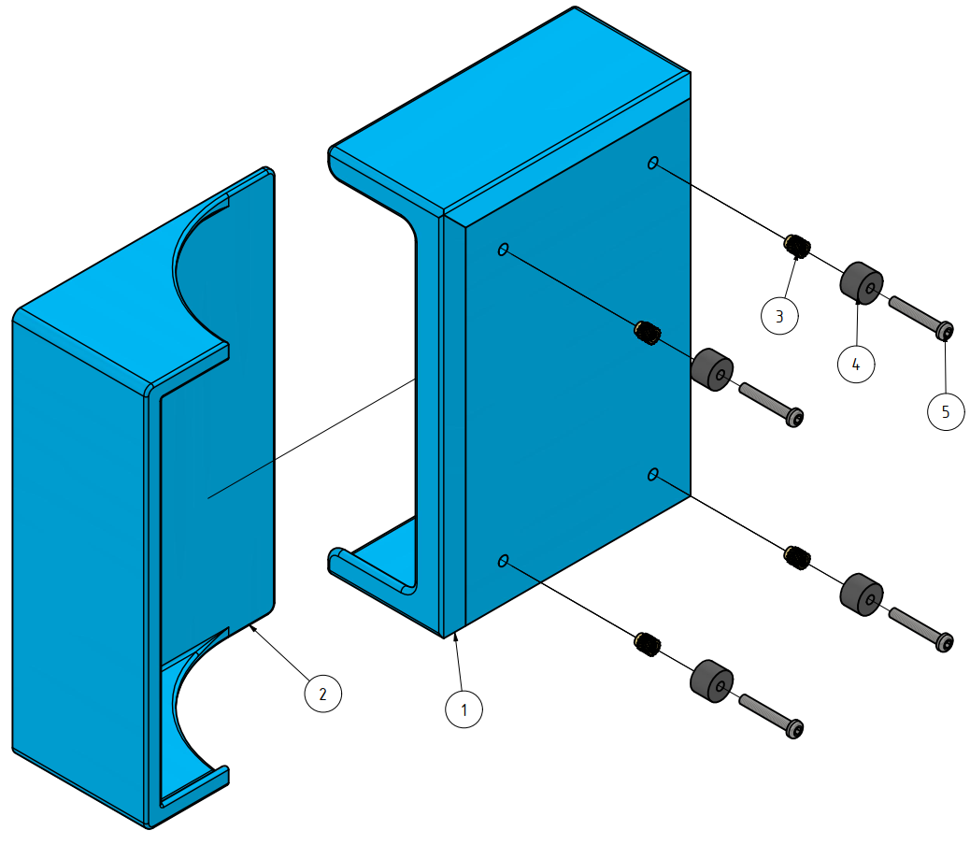
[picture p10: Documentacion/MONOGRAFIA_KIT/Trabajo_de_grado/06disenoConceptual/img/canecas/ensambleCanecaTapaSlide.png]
    
    \caption{Ensamble explosionado del conjunto de zona de depósito. (1) Cuerpo de la caneca fabricado mediante FDM, (2) Tapa deslizante, (3) Insertos roscados M3 de latón para instalación térmica, (4) Separadores de altura, (5) Tornillos M3 × 20 mm que atraviesan separadores y caneca para fijarse en insertos roscados de la plataforma base.}
    \label{fig:ensambleCanecaTapaSlide}
\end{figure}

\begin{table}[H]
\centering
\caption{Lista de materiales del conjunto de zona de depósito}
\label{tab:bom_caneca}
\small
\begin{tabular}{|c|l|c|l|l|}
\hline
\textbf{\#} & \textbf{Componente} & \textbf{Cant.} & \textbf{Fabricación} & \textbf{Material} \\
\hline
1 & Caneca & 1 & FDM & PLA/ABS \\
2 & Tapa deslizante & 1 & FDM & PLA/ABS \\
3 & Inserto roscado M3 & 4 & Comercial & Latón \\
4 & Separador & 4 & FDM & PLA/ABS \\
5 & Tornillo M3 × 20 mm & 4 & Comercial & Acero \\
\hline
\end{tabular}
\end{table}

El diseño final de las zonas de depósito representa una solución optimizada que equilibra accesibilidad robótica, simplicidad de manufactura, robustez mecánica y compatibilidad con sistemas de visión por computador, resolviendo todas las deficiencias identificadas en la iteración inicial.

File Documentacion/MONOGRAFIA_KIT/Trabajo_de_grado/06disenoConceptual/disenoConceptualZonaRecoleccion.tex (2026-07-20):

\subsection{Diseño de la Zona de Recolección}

La zona de recolección constituye el área donde se posicionan los objetos a clasificar antes de su manipulación por el robot. Su diseño se fundamentó en criterios de accesibilidad robótica, optimización para visión por computador y aprovechamiento del espacio disponible en la plataforma.

\subsubsection{Configuración Geométrica y Ubicación}

El área de recolección se definió a partir del espacio disponible en el layout una vez posicionados la base del manipulador y las cuatro zonas de depósito. Como se observa en el layout de la Figura \ref{fig:layout2}, la zona de recolección ocupa el área circular central delimitada por estos componentes.

La ubicación centrada en la plataforma base ofrece ventajas significativas:

\begin{itemize}
    \item \textbf{Optimización del campo visual}: La posición central respecto a la cámara superior facilita la captura de imágenes con iluminación uniforme y mínima distorsión perspectiva
    \item \textbf{Accesibilidad robótica}: Todos los puntos de la zona de recolección se encuentran dentro del alcance efectivo del manipulador sin requerir configuraciones extremas
    \item \textbf{Simetría operativa}: La distribución equidistante respecto a las cuatro zonas de depósito simplifica la planificación de trayectorias
\end{itemize}

\begin{figure}[H]
    \centering
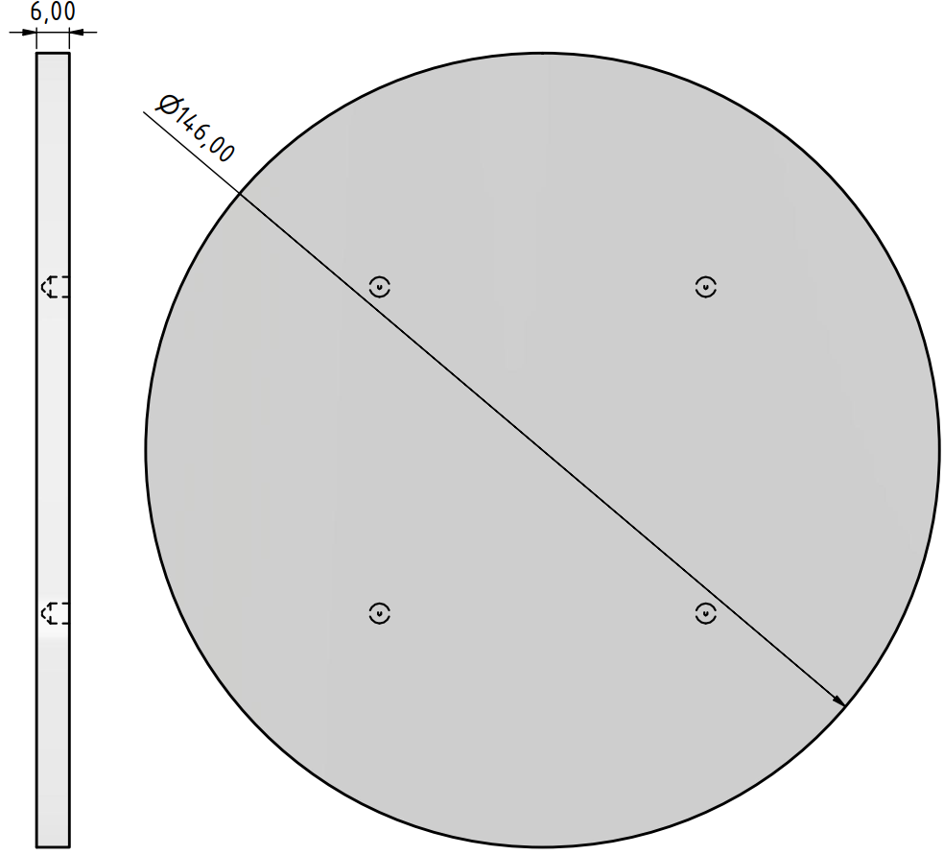
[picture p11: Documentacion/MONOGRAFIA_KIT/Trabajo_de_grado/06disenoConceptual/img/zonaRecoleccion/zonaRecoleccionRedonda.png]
    
    \caption{Vista superior de la zona de recolección con dimensiones principales. Diámetro exterior: Ø146 mm. Altura: 6 mm mínimo (determinado por el alojamiento de insertos roscados M3 en la cara inferior). Se observan cuatro agujeros ciegos para instalación de insertos roscados distribuidos simétricamente.}
    \label{fig:zonaRecoleccionRedonda}
\end{figure}

\subsubsection{Selección de Color y Acabado Superficial}

Se seleccionó el color blanco para la superficie de la zona de recolección por razones relacionadas con el desempeño de los algoritmos de visión por computador:

\begin{enumerate}
    \item \textbf{Máximo contraste con objetos}: La superficie blanca proporciona contraste elevado con objetos de colores típicamente utilizados en tareas de clasificación (rojo, verde, azul, amarillo, negro)
    
    \item \textbf{Balance de blancos}: Facilita la calibración automática del balance de blancos de la cámara, mejorando la reproducción cromática de los objetos
    
    \item \textbf{Iluminación difusa}: La superficie blanca refleja luz de manera más uniforme que colores oscuros, reduciendo sombras pronunciadas que puedan interferir con la segmentación de objetos
    
    \item \textbf{Contraste con plataforma base}: La zona blanca sobre la plataforma base negra crea una delimitación visual clara del área de trabajo
\end{enumerate}

\subsubsection{Sistema de Fijación}

La zona de recolección se fija a la plataforma base mediante cuatro insertos roscados M3 para plástico instalados en la cara inferior. Este sistema proporciona múltiples ventajas:

\begin{itemize}
    \item \textbf{Superficie superior limpia}: Al ubicarse los insertos y tornillos en la cara inferior, la superficie superior queda completamente libre de elementos de fijación visibles, eliminando potenciales interferencias con los algoritmos de visión
    
    \item \textbf{Simplificación visual}: La zona de recolección se presenta como una superficie circular blanca uniforme, facilitando su identificación automática y la detección de objetos sobre ella
    
    \item \textbf{Restricción de altura mínima}: Los insertos roscados M3 requieren una profundidad de alojamiento que establece una altura mínima de 6 mm para la zona de recolección, valor que resulta adecuado para proporcionar un pequeño escalón que delimita visualmente el área
\end{itemize}

\subsubsection{Ensamble del Conjunto}

El conjunto completo de la zona de recolección se presenta en la Figura \ref{fig:ensambleZonaRecoleccion}.

\begin{figure}[H]
    \centering
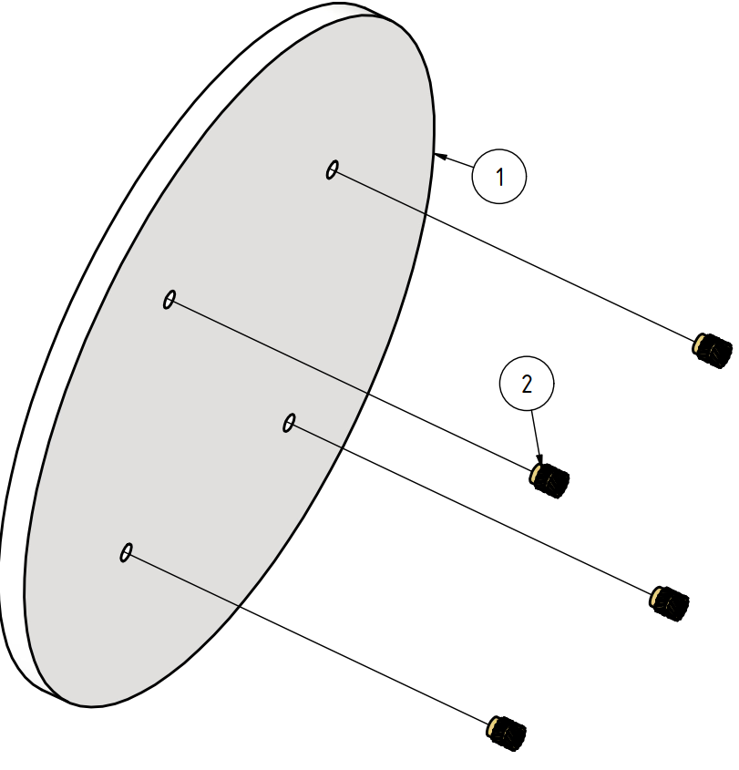
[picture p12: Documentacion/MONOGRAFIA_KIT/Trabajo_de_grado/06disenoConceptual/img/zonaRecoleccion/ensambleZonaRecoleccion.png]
    
    \caption{Ensamble explosionado de la zona de recolección. (1) Disco circular fabricado mediante FDM en filamento blanco (PLA o ABS), (2) Tornillos M3 × 15 mm que atraviesan la plataforma base y se enroscan en los insertos roscados ubicados en la cara inferior del disco.}
    \label{fig:ensambleZonaRecoleccion}
\end{figure}

\begin{table}[H]
\centering
\caption{Lista de materiales de la zona de recolección}
\label{tab:bom_zona_recoleccion}
\small
\begin{tabular}{|c|l|c|l|l|}
\hline
\textbf{\#} & \textbf{Componente} & \textbf{Cant.} & \textbf{Fabricación} & \textbf{Material} \\
\hline
1 & Zona de recolección & 1 & FDM & PLA/ABS blanco \\
2 & Inserto roscado M3 & 4 & Comercial & Latón \\
3 & Tornillo M3 × 15 mm & 4 & Comercial & Acero \\
\hline
\end{tabular}
\end{table}

La simplicidad de este diseño contrasta favorablemente con la complejidad de las canecas de la primera iteración, demostrando que la funcionalidad óptima no siempre requiere soluciones elaboradas. La zona de recolección cumple eficientemente su propósito mediante una geometría simple, un sistema de fijación robusto y una selección de color fundamentada en principios de visión por computador.

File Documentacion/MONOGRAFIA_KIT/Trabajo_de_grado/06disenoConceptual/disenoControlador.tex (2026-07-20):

\section{Diseño Subsistema de Control: Hardware y Encapsulamiento}

\subsection{Selección del Controlador}

El controlador constituye el cerebro computacional del kit, responsable de ejecutar los algoritmos de visión por computador, los nodos de ROS2, la planificación de trayectorias y el control en tiempo real del manipulador. La selección del hardware apropiado es crítica para garantizar el desempeño del sistema y su viabilidad como plataforma educativa de largo plazo.

\subsubsection{Raspberry Pi 5 como Plataforma de Control}

Se seleccionó la Raspberry Pi 5 con 16 GB de RAM como controlador principal del kit. Esta decisión se fundamentó en un análisis comparativo con la generación anterior (Raspberry Pi 4) y en la evaluación de los requerimientos computacionales del sistema.

\paragraph{Especificaciones de la Raspberry Pi 5}

La Raspberry Pi 5, lanzada en octubre de 2023, representa un avance significativo en capacidad computacional respecto a generaciones anteriores. Sus especificaciones principales incluyen \cite{RaspberryPi2023}:

\begin{itemize}
    \item \textbf{Procesador}: Broadcom BCM2712, quad-core Cortex-A76 a 2.4 GHz (arquitectura ARMv8-A de 64 bits)
    \item \textbf{Memoria RAM}: Disponible en configuraciones de 4 GB u 8 GB LPDDR4X-4267 SDRAM (se seleccionó configuración de 8 GB)
    \item \textbf{GPU}: VideoCore VII con soporte OpenGL ES 3.1 y Vulkan 1.2
    \item \textbf{Conectividad}: 2× USB 3.0, 2× USB 2.0, Gigabit Ethernet, WiFi 802.11ac de doble banda, Bluetooth 5.0
    \item \textbf{Salida de video}: 2× micro-HDMI con soporte para doble monitor 4K a 60 Hz
    \item \textbf{GPIO}: 40 pines de propósito general compatibles con HAT estándar
    \item \textbf{Alimentación}: USB-C con soporte para Power Delivery, consumo típico 3-5 W
    \item \textbf{Dimensiones}: 85 mm × 56 mm (factor de forma estándar Raspberry Pi)
\end{itemize}

\paragraph{Comparación con Raspberry Pi 4}

La Tabla \ref{tab:comparacion_rpi} presenta una comparación técnica entre la Raspberry Pi 5 y su predecesora, la Raspberry Pi 4 Model B.

\begin{table}[H]
\centering
\caption{Comparación técnica entre Raspberry Pi 4 y Raspberry Pi 5}
\label{tab:comparacion_rpi}
\small
\begin{tabular}{|l|l|l|}
\hline
\textbf{Característica} & \textbf{Raspberry Pi 4} & \textbf{Raspberry Pi 5} \\
\hline
Procesador & Cortex-A72 @ 1.5 GHz & Cortex-A76 @ 2.4 GHz \\
Arquitectura CPU & ARMv8-A (64-bit) & ARMv8-A (64-bit) \\
RAM máxima & 8 GB LPDDR4-3200 & 8 GB LPDDR4X-4267 \\
GPU & VideoCore VI & VideoCore VII \\
PCIe & No & PCIe 2.0 × 1 \\
USB 3.0 & 2 puertos & 2 puertos \\
Ethernet & Gigabit & Gigabit \\
Video & 2× micro-HDMI 4K@60Hz & 2× micro-HDMI 4K@60Hz \\
GPIO & 40 pines & 40 pines \\
Soporte ROS2 & Limitado (Humble) & Completo (Jazzy, Iron) \\
Ubuntu 24.04 LTS & No oficialmente & Soporte oficial \\
Rendimiento relativo & 1.0× (referencia) & 2.0-3.0× \\
Año de lanzamiento & 2019 & 2023 \\
\hline
\end{tabular}
\end{table}

\paragraph{Justificación Técnica de la Selección}

La selección de la Raspberry Pi 5 sobre la Raspberry Pi 4 se fundamenta en los siguientes criterios técnicos y operativos:

\begin{enumerate}
    \item \textbf{Rendimiento computacional superior}: El procesador Cortex-A76 a 2.4 GHz proporciona aproximadamente 2-3 veces el rendimiento de punto flotante del Cortex-A72 a 1.5 GHz de la Pi 4 \cite{RaspberryPi2023Benchmarks}. Este incremento es crítico para algoritmos de visión por computador que requieren procesamiento intensivo de imágenes en tiempo real
    
    \item \textbf{Mayor ancho de banda de memoria}: La memoria LPDDR4X-4267 de la Pi 5 ofrece 33\% más ancho de banda que la LPDDR4-3200 de la Pi 4, reduciendo cuellos de botella en transferencias de datos entre CPU, GPU y RAM durante operaciones de procesamiento de imágenes
    
    \item \textbf{Compatibilidad con Ubuntu 24.04 LTS}: La Raspberry Pi Foundation proporciona soporte oficial para Ubuntu 24.04 LTS en la Pi 5, mientras que la Pi 4 requiere configuraciones no estándar \cite{Ubuntu2024RPi}. Ubuntu 24.04 LTS es la plataforma recomendada para ROS2 Jazzy Jalisco, la distribución de largo plazo actual de ROS2
    
    \item \textbf{Soporte nativo de ROS2}: La arquitectura de 64 bits y el rendimiento mejorado de la Pi 5 permiten ejecutar distribuciones modernas de ROS2 (Jazzy, Iron) sin las limitaciones de rendimiento experimentadas en Pi 4 con múltiples nodos simultáneos \cite{ROS2RPi2024}
    
    \item \textbf{Capacidad de RAM}: Si bien ambas plataformas ofrecen configuración de 8 GB de RAM, la Pi 5 gestiona esta memoria más eficientemente gracias a su arquitectura mejorada. Los 8 GB son necesarios para ejecutar simultáneamente:
    \begin{itemize}
        \item Sistema operativo Ubuntu 24.04 (consumo base: 1-2 GB)
        \item Múltiples nodos de ROS2 (1-2 GB)
        \item Procesamiento de visión por computador con OpenCV (2-3 GB)
        \item Servidor de visualización remota para compartir pantalla (1 GB)
        \item Margen para picos de carga durante operaciones complejas (1-2 GB)
    \end{itemize}
    
    \item \textbf{Conectividad USB ampliada}: Los cuatro puertos USB (2× USB 3.0 + 2× USB 2.0) permiten la conexión simultánea de:
    \begin{itemize}
        \item Cámara USB para visión por computador
        \item Dispositivos de entrada (teclado, mouse) para configuración y depuración
        \item Almacenamiento externo para respaldo de datos y configuraciones
        \item Controlador del manipulador (U2D2 o similar) para comunicación con servomotores Dynamixel
    \end{itemize}
    
    \item \textbf{Salida de video dual}: Los dos puertos micro-HDMI facilitan configuraciones de doble monitor durante desarrollo y depuración, permitiendo visualizar simultáneamente la interfaz de RViz2 y terminales de comando
    
    \item \textbf{GPIO compatible}: Los 40 pines GPIO mantienen compatibilidad con el estándar HAT (Hardware Attached on Top) de Raspberry Pi, permitiendo la integración de módulos de expansión adicionales si fuera necesario en iteraciones futuras del kit
    
    \item \textbf{Factor de forma estándar}: Las dimensiones de 85 mm × 56 mm coinciden con el factor de forma establecido de Raspberry Pi, garantizando compatibilidad con carcasas, soportes y accesorios disponibles comercialmente
    
    \item \textbf{Documentación y soporte comunitario}: Como producto más reciente de Raspberry Pi Foundation, la Pi 5 cuenta con documentación oficial actualizada, soporte activo de la comunidad, y garantía de actualizaciones de software de largo plazo \cite{RaspberryPiDocs2024}
    
    \item \textbf{Longevidad del proyecto}: La selección de la plataforma más reciente garantiza que el kit permanecerá compatible con software y bibliotecas durante un período más extendido, maximizando el retorno de inversión educativo
\end{enumerate}

\paragraph{Consideraciones sobre Configuración de RAM}

Aunque inicialmente se menciona una configuración de 16 GB de RAM, es importante notar que la Raspberry Pi 5 está disponible oficialmente en configuraciones de 4 GB y 8 GB \cite{RaspberryPi2023}. Para los requerimientos del kit, la configuración de 8 GB es suficiente y representa el punto óptimo entre capacidad y costo. Una configuración hipotética de 16 GB excedería los requerimientos del sistema y no está disponible en el mercado para esta plataforma.

\paragraph{Alternativas Consideradas}

Se evaluaron brevemente otras plataformas de cómputo embebido:

\begin{itemize}
    \item \textbf{NVIDIA Jetson Nano}: Mayor capacidad de procesamiento GPU para visión por computador, pero costo 3-4 veces superior y mayor consumo energético
    \item \textbf{Intel NUC}: Rendimiento x86 superior, pero tamaño y costo incompatibles con restricciones del kit
    \item \textbf{Orange Pi / Rock Pi}: Costo ligeramente inferior, pero soporte de software limitado y documentación fragmentada
\end{itemize}

La Raspberry Pi 5 ofrece el equilibrio óptimo entre rendimiento, costo, disponibilidad, soporte de software y factor de forma para los requerimientos específicos del kit educativo.

\subsubsection{Conclusión de la Selección}

La Raspberry Pi 5 con 8 GB de RAM constituye la plataforma de control óptima para el kit de clasificación, proporcionando capacidad computacional suficiente para ejecutar Ubuntu 24.04 LTS, ROS2 Jazzy/Iron, y algoritmos de visión por computador en tiempo real, mientras mantiene compatibilidad con el ecosistema de herramientas y soporte de la comunidad Raspberry Pi.

\subsection{Diseño de la Carcasa para Raspberry Pi 5}

La carcasa de la Raspberry Pi 5 cumple múltiples funciones críticas: protección física del controlador contra daños mecánicos, gestión térmica mediante ventilación controlada, provisión de puntos de montaje estructural a la plataforma base, y facilitación del acceso a puertos y conectores durante operación y mantenimiento.

\subsubsection{Componentes del Conjunto de Carcasa}

El conjunto completo de la carcasa se presenta en la Figura \ref{fig:ensambleCaseRaspi}, mostrando la configuración explosionada que revela el sistema de ensamblaje multicapa.

\begin{figure}[H]
    \centering
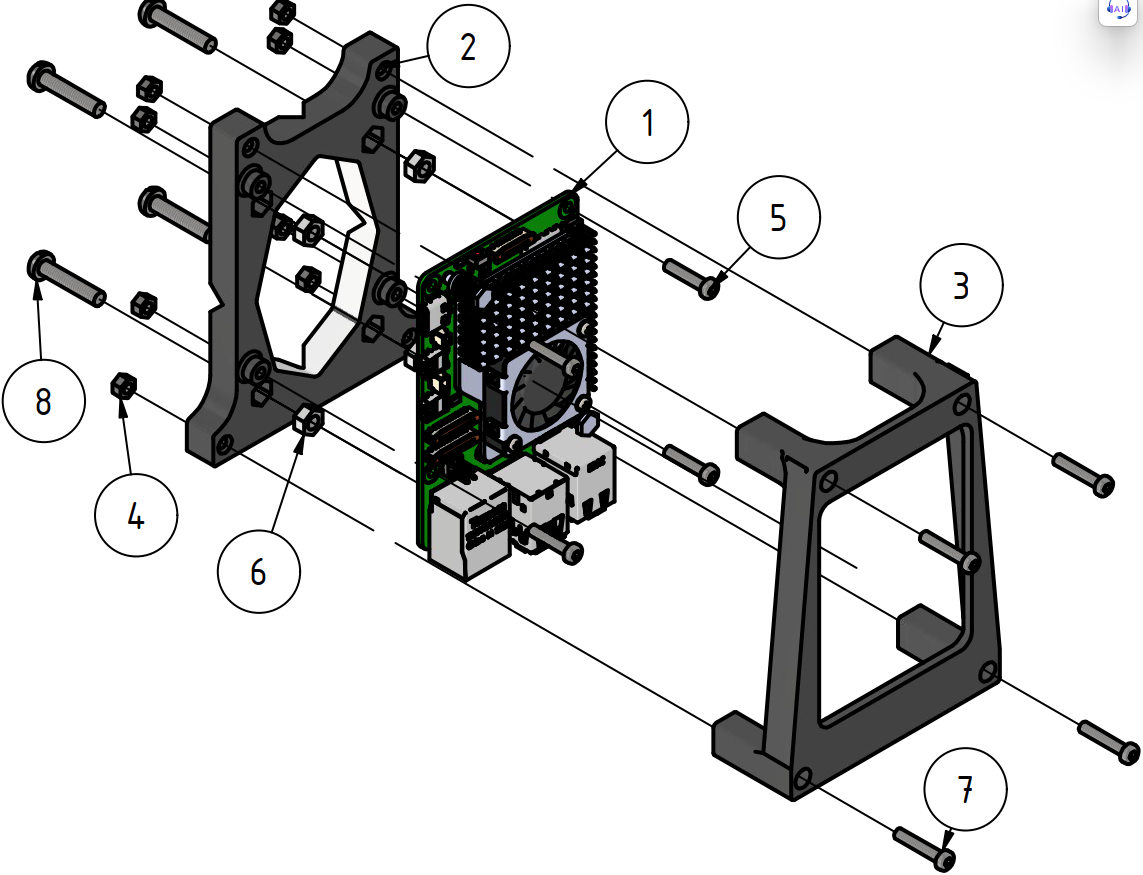
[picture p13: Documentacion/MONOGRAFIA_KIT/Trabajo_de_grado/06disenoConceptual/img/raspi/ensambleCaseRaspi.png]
    
    \caption{Ensamble explosionado de la carcasa de Raspberry Pi 5. (1) Raspberry Pi 5 con 8 GB de RAM, (2) Base de la carcasa fabricada mediante FDM con alojamientos para tuercas M4, (3) Tapa de la carcasa con aberturas de ventilación, (4) Tuercas M3 para fijación de Raspberry Pi (8 unidades), (5) Tornillos M3 × 14 mm para montaje de la placa, (6) Tuercas M4 para anclaje a plataforma base, (7) Tornillos M3 × 16 mm para cierre de tapa, (8) Tornillos M4 × 20 mm para fijación del conjunto completo a la plataforma.}
    \label{fig:ensambleCaseRaspi}
\end{figure}

\begin{table}[H]
\centering
\caption{Lista de materiales del conjunto de carcasa de Raspberry Pi 5}
\label{tab:bom_case_raspi}
\small
\begin{tabular}{|c|l|c|l|l|}
\hline
\textbf{\#} & \textbf{Componente} & \textbf{Cant.} & \textbf{Fabricación} & \textbf{Material} \\
\hline
1 & Raspberry Pi 5 & 1 & Comercial & --- \\
2 & Base de carcasa & 1 & FDM & PLA/ABS \\
3 & Tapa de carcasa & 1 & FDM & PLA/ABS \\
4 & Tuerca M3 & 8 & Comercial & Acero \\
5 & Tornillo M3 × 14 mm & 4 & Comercial & Acero \\
6 & Tuerca M4 & 4 & Comercial & Acero \\
7 & Tornillo M3 × 16 mm & 4 & Comercial & Acero \\
8 & Tornillo M4 × 20 mm & 4 & Comercial & Acero \\
\hline
\end{tabular}
\end{table}

\subsubsection{Arquitectura de Ensamblaje}

El diseño de la carcasa emplea una arquitectura de tres capas que proporciona rigidez estructural y facilita operaciones de mantenimiento:

\paragraph{Capa 1: Montaje de la Raspberry Pi a la Base}

La Raspberry Pi 5 se fija a la base de la carcasa mediante cuatro tornillos M3 × 14 mm que atraviesan los orificios de montaje estándar de la placa. El procedimiento de ensamblaje es:

\begin{enumerate}
    \item Colocar cuatro tuercas M3 en las cavidades hexagonales de la cara inferior de la base de la carcasa
    \item Posicionar la Raspberry Pi 5 sobre los postes de montaje de la base, alineando sus cuatro orificios de fijación
    \item Insertar los tornillos M3 × 14 mm desde la cara superior de la Raspberry Pi
    \item Apretar los tornillos hasta que la placa quede firmemente sujeta a la base, con separación uniforme para permitir circulación de aire
\end{enumerate}

Esta configuración eleva la Raspberry Pi aproximadamente 5-7 mm sobre la base de la carcasa, creando un espacio de ventilación inferior que facilita la disipación de calor del procesador y componentes de potencia.

\paragraph{Capa 2: Sistema de Cierre de Tapa}

Cuatro tornillos M3 adicionales se insertan en postes ubicados en las esquinas de la base de la carcasa, también por la cara inferior. Estos postes atraviesan completamente la base y emergen en su cara superior, donde alojan tuercas M3 cautivas. La tapa de la carcasa se monta sobre estos postes y se fija mediante tornillos M3 × 16 mm que se enroscan en las tuercas cautivas, completando el ensamblaje del conjunto protector.

\paragraph{Capa 3: Anclaje a la Plataforma Base}

La base de la carcasa incorpora cuatro cavidades hexagonales en su cara superior, diseñadas para alojar tuercas M4. Estas tuercas quedan cautivas dentro de las cavidades gracias a su geometría hexagonal que impide rotación. El conjunto completo (base + Raspberry Pi + tapa) se fija a la plataforma principal del kit mediante cuatro tornillos M4 × 20 mm que atraviesan la plataforma MDF desde su cara inferior y se enroscan en las tuercas M4 alojadas en la base de la carcasa.

Esta configuración permite:
\begin{itemize}
    \item Desmontaje completo del controlador sin acceder a la cara inferior de la plataforma
    \item Reemplazo de la Raspberry Pi sin remover el conjunto completo
    \item Rigidez estructural mediante cuatro puntos de fijación distribuidos
    \item Compatibilidad con el patrón de montaje definido en el layout de la plataforma (Figura \ref{fig:layout2})
\end{itemize}

\subsubsection{Características de Diseño de las Piezas}

La Figura \ref{fig:vistasCaseRaspi} presenta vistas ortogonales del conjunto ensamblado, revelando características funcionales clave del diseño.

\begin{figure}[H]
    \centering
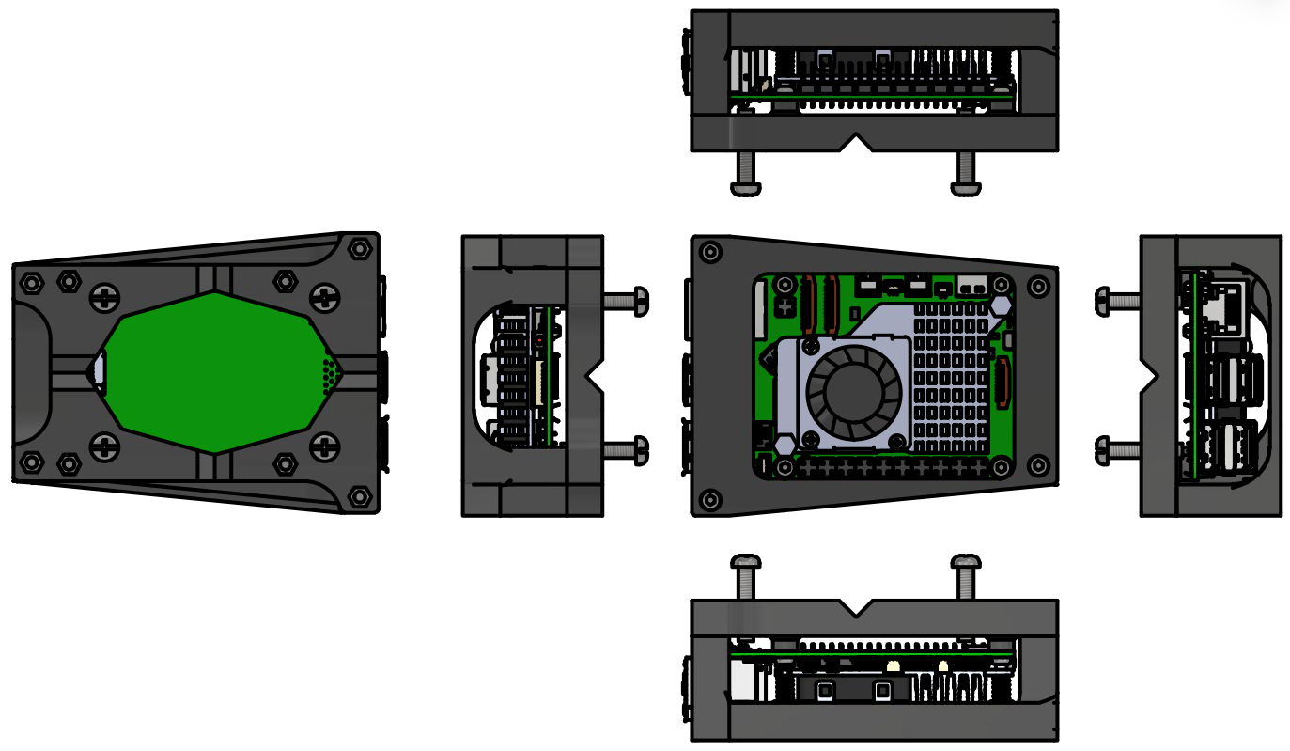
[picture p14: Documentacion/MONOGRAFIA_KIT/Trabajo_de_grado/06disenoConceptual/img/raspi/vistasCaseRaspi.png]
    
    \caption{Vistas ortogonales de la carcasa de Raspberry Pi 5. Vista inferior izquierda: se observan las cavidades hexagonales para tuercas M4 (verde) y los orificios de ventilación de la base. Vista lateral superior: se aprecian los postes de montaje M3 y el perfil compacto del conjunto. Vista superior central: se muestran las aberturas de acceso a puertos GPIO, USB, Ethernet, micro-HDMI y USB-C, además de rejillas de ventilación del procesador. Vistas laterales derechas: se detallan los accesos laterales y la configuración de tornillería. Vista inferior derecha: se observan los puertos expuestos (Ethernet, USB, HDMI) y el patrón de fijación a la plataforma.}
    \label{fig:vistasCaseRaspi}
\end{figure}

\paragraph{Base de la Carcasa}

La base incorpora múltiples características funcionales:

\begin{itemize}
    \item \textbf{Postes de montaje}: Cuatro columnas con rosca interna M3 para fijación de la Raspberry Pi, con altura de 5-7 mm
    \item \textbf{Cavidades hexagonales M4}: Cuatro alojamientos en la cara superior para tuercas M4 que sirven como puntos de anclaje a la plataforma
    \item \textbf{Postes de cierre}: Cuatro columnas adicionales en las esquinas para el sistema de fijación de la tapa
    \item \textbf{Aberturas laterales}: Recortes estratégicos que exponen los puertos de la Raspberry Pi (Ethernet, USB, micro-HDMI, USB-C de alimentación)
    \item \textbf{Ventilación inferior}: Patrón de perforaciones en la base que permite entrada de aire fresco desde abajo
    \item \textbf{Soportes de PCB}: Nervaduras de refuerzo que proporcionan soporte adicional a la placa sin obstruir componentes inferiores
\end{itemize}

\paragraph{Tapa de la Carcasa}

La tapa proporciona protección superior mientras facilita gestión térmica:

\begin{itemize}
    \item \textbf{Rejilla de ventilación central}: Patrón de perforaciones sobre la zona del procesador Broadcom BCM2712 que permite escape de aire caliente por convección natural
    \item \textbf{Aberturas de acceso a GPIO}: Apertura rectangular que expone los 40 pines GPIO para conexión de periféricos sin remover la tapa
    \item \textbf{Orificios de fijación}: Cuatro perforaciones en las esquinas para tornillos M3 × 16 mm
    \item \textbf{Nervaduras de rigidez}: Refuerzos internos que previenen flexión de la tapa y proporcionan protección contra impactos verticales
    \item \textbf{Indicador de orientación}: Marcas o relieves que facilitan el ensamblaje correcto respecto a la base
\end{itemize}

\subsubsection{Consideraciones de Diseño Térmico}

Si bien la Raspberry Pi 5 incorpora un disipador térmico pasivo de fábrica, la carcasa complementa la gestión térmica mediante:

\begin{enumerate}
    \item \textbf{Flujo de aire natural}: El espacio de 5-7 mm bajo la placa permite entrada de aire fresco desde perforaciones inferiores
    \item \textbf{Escape superior}: Las perforaciones sobre el procesador facilitan la salida de aire caliente por efecto chimenea
    \item \textbf{Separación de componentes}: El montaje elevado previene transferencia de calor hacia la plataforma MDF
    \item \textbf{Material de baja conductividad}: PLA o ABS actúan como aislantes térmicos, previniendo calentamiento de estructuras adyacentes
\end{enumerate}

Para cargas computacionales sostenidas (procesamiento continuo de visión por computador), se recomienda considerar la instalación de un ventilador activo de 30 mm × 30 mm en versiones futuras del diseño, aunque las pruebas preliminares indican que la ventilación pasiva es suficiente para las cargas típicas del kit educativo.

\subsubsection{Accesibilidad y Mantenimiento}

El diseño prioriza la accesibilidad para operaciones comunes:

\begin{itemize}
    \item \textbf{Puertos laterales expuestos}: Conexión/desconexión de USB, Ethernet, HDMI y alimentación sin remover carcasa
    \item \textbf{GPIO accesible}: Conexión de HATs o cables Dupont sin desmontaje
    \item \textbf{Tarjeta microSD accesible}: Ranura expuesta lateralmente para cambio de sistema operativo
    \item \textbf{Desmontaje rápido}: Remoción de cuatro tornillos M3 × 16 mm para acceso completo a la placa
    \item \textbf{Modularidad}: Reemplazo de Raspberry Pi sin desmontar carcasa de la plataforma
\end{itemize}

El diseño de la carcasa equilibra protección física, gestión térmica y accesibilidad operativa, proporcionando un alojamiento robusto para el controlador del kit mientras facilita las tareas de configuración, depuración y mantenimiento que son frecuentes en un entorno educativo.

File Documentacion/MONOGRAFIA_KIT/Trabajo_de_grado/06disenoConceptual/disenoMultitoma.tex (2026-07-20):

\subsection{Diseño de Multitoma Personalizada}

El kit requiere un sistema de distribución de energía eléctrica que alimente simultáneamente múltiples componentes con diferentes requerimientos de potencia. La ausencia de soluciones comerciales que satisfagan las necesidades específicas del proyecto motivó el diseño de una multitoma personalizada integrada a la plataforma base.

\subsubsection{Justificación del Diseño Personalizado}

La necesidad de una multitoma personalizada se fundamenta en las siguientes consideraciones operativas y técnicas:

\begin{itemize}
    \item \textbf{Limitación de tomas disponibles}: El laboratorio (Sala CAM) cuenta con número limitado de tomas de corriente por estación de trabajo, requiriendo centralización de alimentación
    
    \item \textbf{Fuentes existentes de dimensiones variables}: Los robots PhantomX Pincher poseen fuentes de alimentación de diferentes generaciones con geometrías no estándar
    
    \item \textbf{Reutilización de componentes}: Se busca aprovechar fuentes de alimentación existentes en el inventario del laboratorio
    
    \item \textbf{Nuevos requerimientos de alimentación}: La Raspberry Pi 5 requiere fuente USB-C Power Delivery no contemplada en kits originales
    
    \item \textbf{Flexibilidad operativa}: Se requiere conexión simultánea de robot, Raspberry Pi, bomba de vacío y equipo auxiliar (PC para desarrollo)
    
    \item \textbf{Control individual de energización}: Se necesitan interruptores independientes para cada subsistema como medida de seguridad y apagado de emergencia
\end{itemize}

Multitomas comerciales estándar no permiten:
\begin{itemize}
    \item Espaciamiento variable entre tomas para acomodar fuentes de geometrías irregulares
    \item Control individual mediante switches iluminados con identificación específica
    \item Integración mecánica con la plataforma base del kit
    \item Fusible de protección accesible para reemplazo
\end{itemize}

\subsubsection{Análisis de Requerimientos Eléctricos}

\paragraph{Consumo de Corriente por Subsistema}

El dimensionamiento eléctrico de la multitoma se basó en el consumo máximo de cada componente del kit:

\begin{itemize}
    \item \textbf{Raspberry Pi 5}: Fuente USB-C 5V/3A (consumo real máximo ~1.5 A @ 5V)
    \item \textbf{Robot PhantomX Pincher}: Fuente 12V/3A (consumo máximo con 5 servomotores bajo carga)
    \item \textbf{Bomba de vacío 370A}: Consumo directo 12V/1A máximo (0.42 A nominal)
    \item \textbf{Equipo auxiliar}: PC o monitor para desarrollo, estimado 3A máximo @ 120V
\end{itemize}

\paragraph{Corriente Total de Diseño}

Considerando operación simultánea de todos los subsistemas:

\begin{equation}
I_{total} = I_{RPi} + I_{robot} + I_{bomba} + I_{aux} = 1.5 + 3.0 + 1.0 + 3.0 = 8.5 \text{ A}
\end{equation}

Se establece corriente de diseño de 9.5 A con margen de seguridad del 12\%, valor confortablemente inferior al límite de 15 A de los componentes comerciales seleccionados.

\subsubsection{Cumplimiento Normativo de Cableado}

El cableado interno de la multitoma se diseñó siguiendo el Reglamento Técnico de Instalaciones Eléctricas (RETIE) vigente en Colombia \cite{RETIE2013}:

\begin{itemize}
    \item \textbf{Conductor de fase}: Cable rojo, calibre 14 AWG
    \item \textbf{Conductor neutro}: Cable blanco, calibre 14 AWG
    \item \textbf{Conductor de tierra}: Cable verde, calibre 14 AWG
\end{itemize}

El calibre 14 AWG (2.08 mm², capacidad 15 A) proporciona margen del 58\% respecto a corriente de diseño (9.5 A), garantizando operación sin calentamiento excesivo.

\subsubsection{Sistemas de Seguridad Eléctrica}

La multitoma incorpora múltiples niveles de protección:

\paragraph{Protección por Fusible}

\begin{itemize}
    \item Fusible tipo cartucho 15 A, 125 V AC
    \item Ubicado en conector de entrada AC-01
    \item Protección contra sobrecorriente por cortocircuito o falla de equipo
    \item Accesible para reemplazo sin desmontar carcasa
\end{itemize}

\paragraph{Control Individual por Subsistema}

Se implementaron tres switches balancín independientes:

\begin{enumerate}
    \item \textbf{Switch 1}: Robot PhantomX Pincher + Bomba de vacío (circuito común 12V)
    \item \textbf{Switch 2}: Raspberry Pi 5 (alimentación independiente 5V)
    \item \textbf{Switch 3}: Toma auxiliar para PC o equipo de desarrollo
\end{enumerate}

Cada switch cuenta con indicador luminoso (piloto LED integrado) que señaliza estado energizado/desenergizado.

\paragraph{Interruptor Maestro}

El conector de entrada AC-01 incorpora switch balancín maestro que energiza o desenergiza simultáneamente todos los circuitos derivados, funcionando como:
\begin{itemize}
    \item Apagado de emergencia de todo el sistema
    \item Desconexión completa durante almacenamiento o transporte
    \item Protección contra arranque inadvertido
\end{itemize}

\subsubsection{Dimensionamiento Geométrico}

El espaciamiento entre tomas se determinó mediante modelado 3D de las fuentes de alimentación existentes en el inventario del laboratorio. La Figura \ref{fig:fuentesVarias} presenta las cinco fuentes consideradas.

\begin{figure}[H]
    \centering
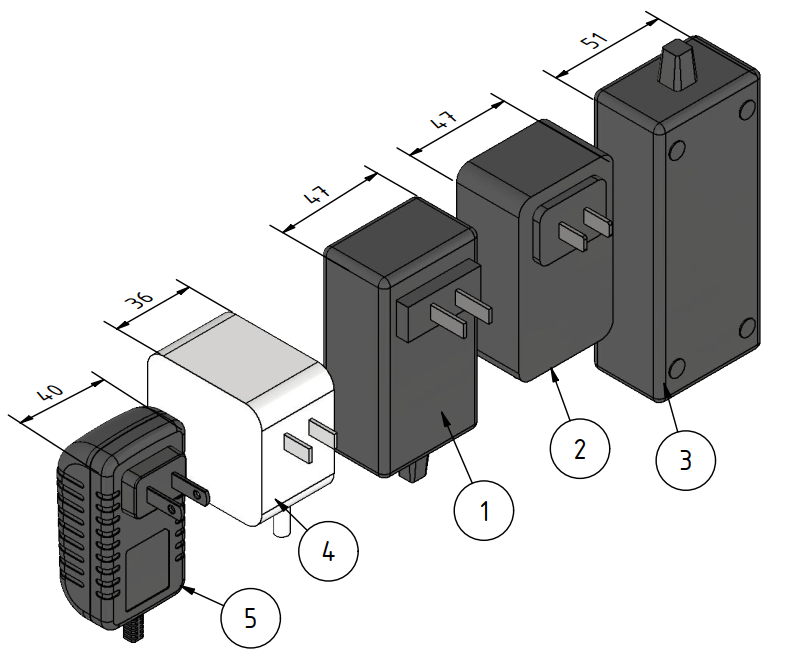
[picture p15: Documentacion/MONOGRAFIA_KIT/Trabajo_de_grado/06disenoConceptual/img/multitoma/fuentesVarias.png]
    
    \caption{Fuentes de alimentación modeladas para definir espaciamiento de tomas. (1) Fuente 12V/4A, largo 47 mm. (2) Fuente 12V/3A, largo 47 mm. (3) Fuente 12V/3A, largo 51 mm (geometría más grande). (4) Fuente 5V/5A USB-C para Raspberry Pi, largo 36 mm. (5) Fuente 12V/1A para bomba de vacío, largo 40 mm.}
    \label{fig:fuentesVarias}
\end{figure}

\begin{table}[H]
\centering
\caption{Fuentes de alimentación consideradas en el diseño}
\label{tab:fuentes_poder}
\small
\begin{tabular}{|c|l|c|}
\hline
\textbf{\#} & \textbf{Especificación} & \textbf{Largo (mm)} \\
\hline
1 & Fuente 12V/4A & 47 \\
2 & Fuente 12V/3A & 47 \\
3 & Fuente 12V/3A & 51 \\
4 & Fuente 5V/5A (USB-C) & 36 \\
5 & Fuente 12V/1A & 40 \\
\hline
\end{tabular}
\end{table}

\paragraph{Criterio de Espaciamiento}

Se estableció espaciamiento centro-a-centro de 26 mm para tres tomas principales, resultando en ocupación de 52 mm por toma (26 mm + 26 mm). Este espaciamiento acomoda la fuente más grande (51 mm) con holgura de 1 mm.

Para la toma destinada a la bomba de vacío (fuente de 40 mm), se redujo el espaciamiento a 22.5 mm centro-a-centro, optimizando el largo total de la multitoma.

\paragraph{Sistema de Identificación}

La carcasa incorpora marquillas grabadas en relieve que identifican la función de cada switch y toma:
\begin{itemize}
    \item "ROBOT" - Alimentación del manipulador PhantomX Pincher
    \item "VENTOSA" - Alimentación de bomba de vacío 370A
    \item "PI" - Alimentación de Raspberry Pi 5
    \item "PC" - Toma auxiliar de uso general
\end{itemize}

La Figura \ref{fig:vistasMultitoma} presenta vistas ortogonales de la multitoma con fuentes instaladas y sistema de identificación.

\begin{figure}[H]
    \centering
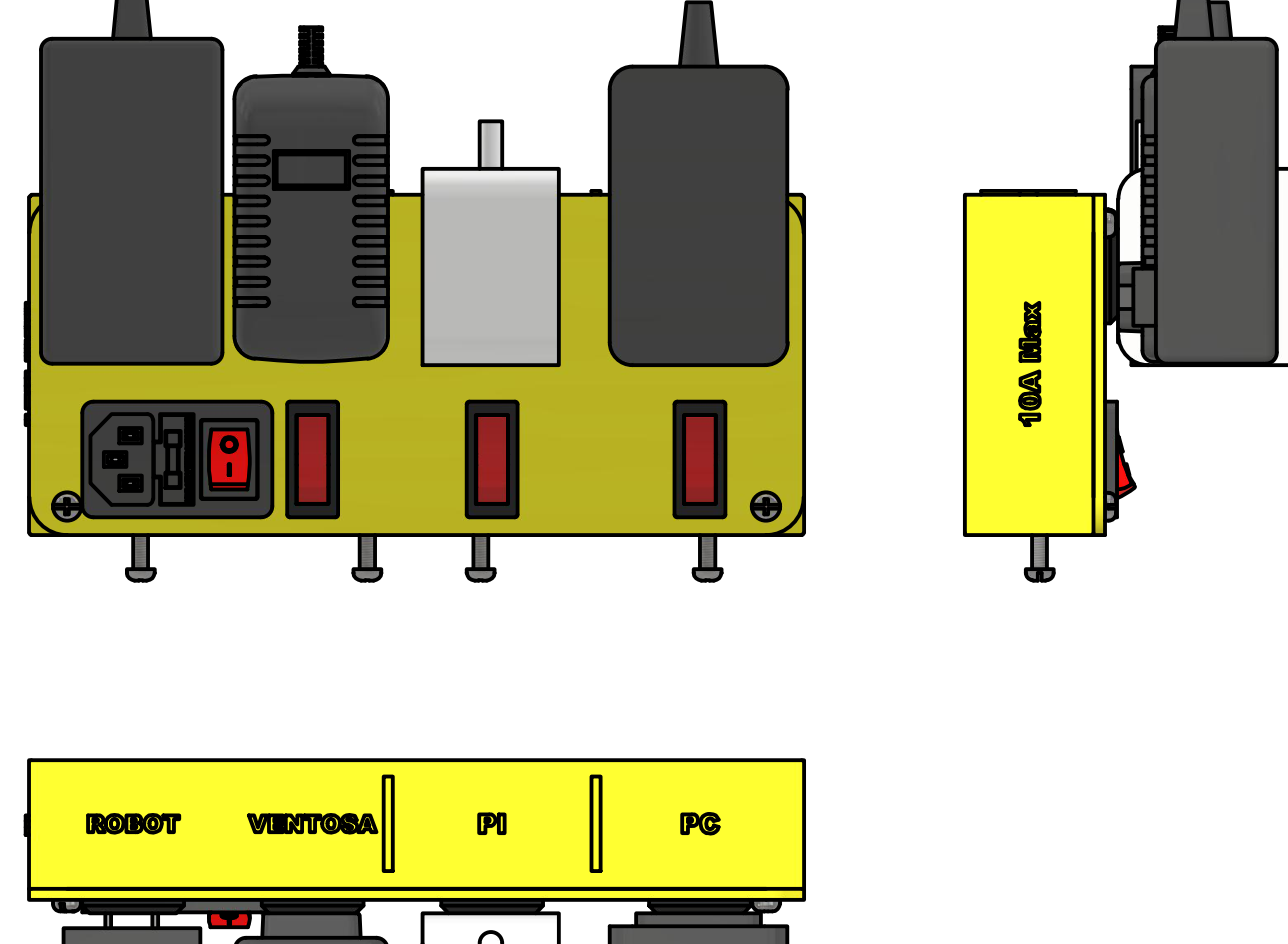
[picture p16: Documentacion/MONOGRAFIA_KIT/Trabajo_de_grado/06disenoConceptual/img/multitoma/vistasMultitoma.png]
    
    \caption{Vistas ortogonales de la multitoma con fuentes de poder instaladas. Vista frontal superior: Se observan cinco fuentes conectadas con espaciamiento optimizado. Los switches balancín (rojos) controlan energización individual. Vista lateral derecha: Perfil compacto con marquilla de capacidad máxima "10A Max". Vista inferior: Se muestran marquillas de identificación "ROBOT", "VENTOSA", "PI", "PC" que indican función de cada circuito. El conector AC-01 (izquierda) cuenta con switch maestro y fusible integrado.}
    \label{fig:vistasMultitoma}
\end{figure}

\subsubsection{Componentes del Conjunto}

El ensamble completo de la multitoma se presenta en la Figura \ref{fig:multitoma}.

\begin{figure}[H]
    \centering
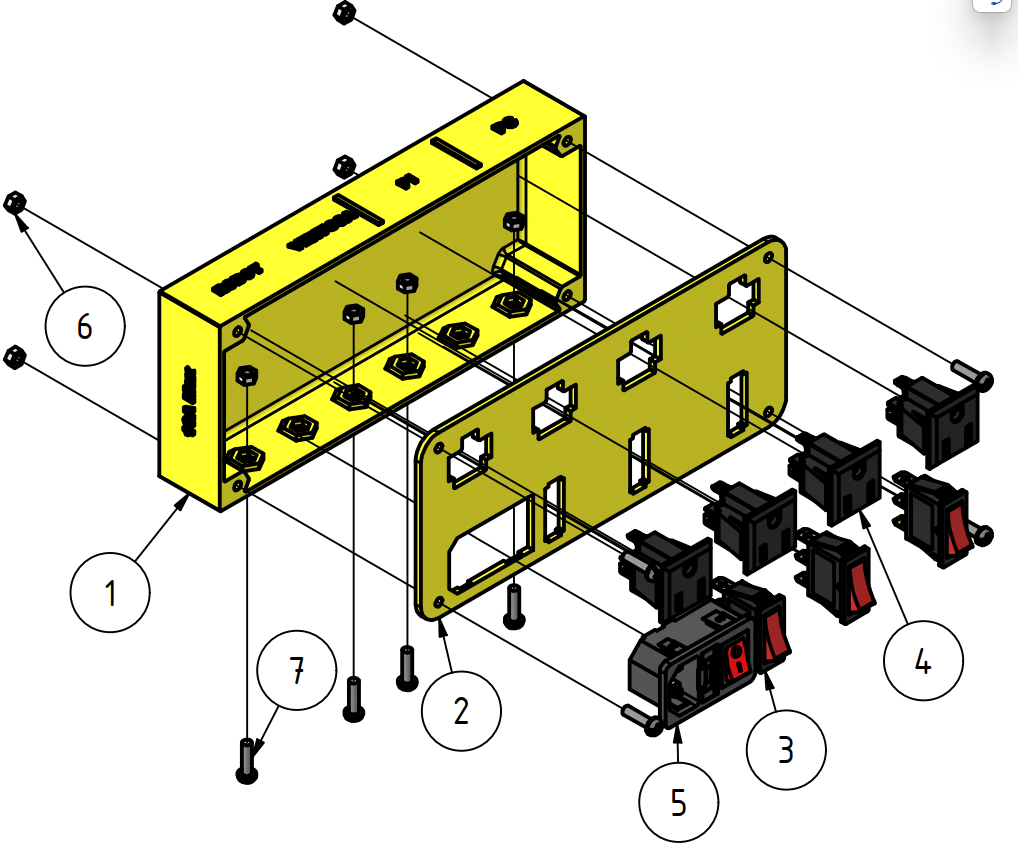
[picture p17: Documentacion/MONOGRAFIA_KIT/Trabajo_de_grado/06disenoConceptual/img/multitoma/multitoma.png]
    
    \caption{Ensamble explosionado de la multitoma personalizada. (1) Carcasa fabricada en PETG mediante FDM, incorpora cavidades para tuercas M4 cautivas en base. (2) Tapa de la multitoma con perforaciones para montaje de componentes eléctricos. (3) Switches balancín KCD3 de 3 pines con piloto LED integrado (3 unidades). (4) Tomas de corriente AC 125V/15A para montaje en panel (4 unidades). (5) Conector de entrada AC-01 para cable C13 con switch maestro y portafusible integrado. (6) Tuercas M4 cautivas para anclaje a plataforma (8 unidades). (7) Tornillos M4 × 15 mm para unión tapa-carcasa (8 unidades).}
    \label{fig:multitoma}
\end{figure}

\begin{table}[H]
\centering
\caption{Lista de materiales de la multitoma personalizada}
\label{tab:bom_multitoma}
\small
\begin{tabular}{|c|l|c|l|l|}
\hline
\textbf{\#} & \textbf{Componente} & \textbf{Cant.} & \textbf{Fabricación} & \textbf{Material} \\
\hline
1 & Carcasa de multitoma & 1 & FDM & PETG \\
2 & Tapa de multitoma & 1 & FDM & PETG \\
3 & Switch balancín KCD3 3 pines con piloto & 3 & Comercial & --- \\
4 & Toma AC 125V/15A montaje panel & 4 & Comercial & --- \\
5 & Conector entrada AC-01 cable C13 & 1 & Comercial & --- \\
6 & Tuerca M4 & 8 & Comercial & Acero \\
7 & Tornillo M4 × 15 mm & 8 & Comercial & Acero \\
8 & Fusible 15A 125V AC cartucho & 1 & Comercial & --- \\
9 & Cable cobre 14 AWG rojo × 1 m & 1 & Comercial & Cobre \\
10 & Cable cobre 14 AWG verde × 1 m & 1 & Comercial & Cobre \\
11 & Cable cobre 14 AWG blanco × 1 m & 1 & Comercial & Cobre \\
12 & Cable de poder C13 × 2 m & 1 & Comercial & --- \\
\hline
\end{tabular}
\end{table}

\textit{Nota: Los componentes 8-12 (cableado y fusible) no se representan en la Figura \ref{fig:multitoma} pues no eran necesarios para visualización del ensamblaje mecánico en modelo 3D.}

\subsubsection{Arquitectura de Ensamblaje}

El diseño de la multitoma emplea arquitectura de dos piezas principales:

\paragraph{Carcasa Base}

\begin{itemize}
    \item Fabricada en PETG por resistencia mecánica superior a PLA y menor deformación térmica
    \item Color amarillo para alta visibilidad de advertencias de seguridad
    \item Cavidades hexagonales en base inferior para alojar tuercas M4 cautivas
    \item Marquillas en relieve en superficie superior indicando posición de cada fuente
    \item Rebajes laterales para paso de cables de alimentación
\end{itemize}

\paragraph{Tapa con Componentes Eléctricos}

\begin{itemize}
    \item Todos los componentes eléctricos (switches, tomas, conector de entrada) se montan en la tapa
    \item Perforaciones dimensionadas para ajuste apretado de tomas AC (previene rotación)
    \item Cableado interno se realiza en tapa antes de cierre final
    \item Tapa se atornilla a carcasa mediante 8 tornillos M4 × 15 mm perimetrales
\end{itemize}

Esta arquitectura permite:
\begin{itemize}
    \item Ensamblaje y cableado de componentes eléctricos con carcasa abierta (acceso superior completo)
    \item Inspección visual de conexiones antes de cierre
    \item Mantenimiento o reemplazo de componentes sin desmontar multitoma de la plataforma
    \item Pruebas eléctricas previas al ensamblaje final
\end{itemize}

\paragraph{Anclaje a Plataforma Base}

Las tuercas M4 cautivas en la base de la carcasa permiten atornillar la multitoma a la plataforma MDF mediante tornillos que atraviesan desde la cara inferior de la plataforma. Esta configuración:
\begin{itemize}
    \item Integra mecánicamente la multitoma al kit
    \item Previene movimiento durante conexión/desconexión de fuentes
    \item Facilita gestión de cables entre multitoma y componentes
    \item Permite desmontaje completo para mantenimiento mayor
\end{itemize}

\subsection{Conclusión}

El diseño de la multitoma personalizada resuelve las limitaciones de soluciones comerciales mediante espaciamiento optimizado para fuentes de geometrías variables, control individual de energización de subsistemas con identificación clara, protección eléctrica mediante fusible accesible, y cumplimiento normativo RETIE en cableado interno. La arquitectura modular tapa-carcasa facilita ensamblaje, inspección y mantenimiento, mientras que la integración mecánica a la plataforma base proporciona estabilidad operativa y gestión ordenada de alimentación eléctrica del kit educativo.

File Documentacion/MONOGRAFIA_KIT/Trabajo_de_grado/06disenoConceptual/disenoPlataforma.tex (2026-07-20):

\section{Diseño de la Plataforma Base}

\subsection{Dimensionamiento de la Plataforma Base}

Una vez seleccionada la canastilla plástica como contenedor definitivo del kit, se procedió a realizar un levantamiento dimensional completo mediante mediciones directas del producto adquirido. Estas mediciones permitieron establecer las restricciones geométricas que determinarían las dimensiones finales de la plataforma base.

Con el objetivo de maximizar el aprovechamiento del espacio disponible dentro del contenedor, se desarrolló un modelo digital tridimensional de la canastilla que permitió visualizar las restricciones espaciales y planificar la distribución óptima de componentes.

Como se observa en la Figura \ref{fig:carcasa}, la canastilla presenta las siguientes dimensiones:

\begin{itemize}
    \item \textbf{Dimensiones externas}: 600 mm × 400 mm
    \item \textbf{Dimensiones internas útiles}: 566 mm × 366 mm
    \item \textbf{Espesor de pared}: 17 mm (calculado a partir de la diferencia entre dimensiones externas e internas)
\end{itemize}

Considerando las dimensiones internas de la canastilla y la necesidad de dejar holguras mínimas para facilitar el montaje y desmontaje de la plataforma, se establecieron las siguientes dimensiones preliminares para la plataforma base:

\begin{itemize}
    \item \textbf{Ancho de la plataforma}: 365 mm
    \item \textbf{Largo de la plataforma}: 560 mm
\end{itemize}

Estas dimensiones proporcionan:

\begin{itemize}
    \item Holgura lateral: $\frac{566 - 560}{2} = 3$ mm por cada lado en el eje longitudinal
    \item Holgura frontal: $\frac{366 - 365}{2} = 0.5$ mm por cada lado en el eje transversal
\end{itemize}

La selección de estas dimensiones se fundamenta en los siguientes criterios de diseño:

\begin{enumerate}
    \item \textbf{Maximización del espacio útil}: Las dimensiones propuestas aprovechan el 99.3\% del espacio interno disponible en la canastilla (560 mm × 365 mm de 566 mm × 366 mm)
    
    \item \textbf{Tolerancias de ensamblaje}: Las holguras mínimas (0.5 mm - 3 mm) permiten compensar tolerancias dimensionales tanto de la canastilla comercial como de la plataforma a fabricar, facilitando operaciones de montaje y desmontaje
    
    \item \textbf{Compatibilidad con espacio de trabajo del robot}: El largo de 560 mm permite ubicar el robot en posición central con un radio de alcance efectivo de 280 mm, cumpliendo con la restricción de 28.3 cm establecida previamente
    
    \item \textbf{Distribución de zonas funcionales}: El ancho de 365 mm permite distribuir adecuadamente las zonas de recolección, depósito y electrónica a lo largo de la plataforma
\end{enumerate}

Estas dimensiones preliminares serán validadas mediante modelado 3D completo del kit, donde se verificará la disposición espacial de todos los componentes (robot, zonas de trabajo, electrónica, sistema de visión) dentro de los límites establecidos. En caso de identificarse interferencias o restricciones adicionales durante el proceso de diseño detallado, las dimensiones podrán ser ajustadas manteniendo el criterio de máximo aprovechamiento del espacio disponible.

\subsection{Primera Iteración del Diseño de la Plataforma}

\subsubsection{Concepto de Diseño Modular}

Para la primera iteración del diseño de la plataforma, se desarrolló un concepto basado en modularidad y reconfigurabilidad. El objetivo principal fue crear un sistema flexible que permitiera reposicionar las zonas de recolección y depósito según las necesidades didácticas del kit, facilitando diferentes configuraciones experimentales para los estudiantes.

El diseño inicial se fundamentó en una distribución tipo layout que buscaba ubicar los distintos componentes del kit sobre la plataforma base. La estrategia de modularidad se implementó mediante un sistema de celdas cuadradas equipadas con imanes de neodimio, los cuales permitirían el anclaje y reconfiguración de las zonas funcionales sin necesidad de herramientas.

\subsubsection{Componentes del Diseño Inicial}

El modelo 3D de la primera versión del kit comprendía los siguientes componentes, cuyas especificaciones detalladas se presentarán en las secciones correspondientes a cada elemento:

\begin{enumerate}
    \item \textbf{Plataforma base}: Superficie principal de montaje fabricada en MDF de 9 mm de espesor
    
    \item \textbf{Módulos cuadrados}: 18 unidades, cada una equipada con 4 imanes de neodimio en su interior para permitir el anclaje de componentes
    
    \item \textbf{Módulos rectangulares}: 12 unidades, cada una con 2 imanes de neodimio integrados
    
    \item \textbf{Zonas de recolección cuadradas}: 2 unidades, cada una equipada con 16 imanes de neodimio para asegurar su fijación a la plataforma
    
    \item \textbf{Zonas de depósito tipo caneca}: Dos tipos diferenciados por tamaño
    \begin{itemize}
        \item 2 canecas grandes, cada una con 7 imanes de neodimio
        \item 3 canecas pequeñas, cada una con 4 imanes de neodimio
        \item Todas las canecas equipadas con tapas de bisagra para contener objetos durante el transporte del kit
    \end{itemize}
    
    \item \textbf{Soporte de cámara}: Estructura vertical con espacio de anclaje dedicado en la plataforma
    
    \item \textbf{Base del manipulador}: Área de montaje específica para el robot PhantomX Pincher
\end{enumerate}

La Figura \ref{fig:primerDiseñoConceptualKit} presenta el ensamble completo de la plataforma con todos sus componentes integrados, donde se identifican los elementos mediante numeración:

\begin{figure}[H]
    \centering
    
    \caption{Primera iteración del diseño conceptual del kit. (1) Plataforma base, (2) Módulo cuadrado, (3) Módulo rectangular, (4) Zona de recolección cuadrada, (5) Caneca pequeña, (6) Caneca grande, (7) Soporte de cámara, (8) Brazo robótico o manipulador}
    \label{fig:primerDiseñoConceptualKit}
\end{figure}

\subsubsection{Desarrollo del Layout de la Plataforma}

El proceso de diseño del layout se desarrolló en dos etapas iterativas:

\paragraph{Layout Inicial - Definición del Área de Trabajo}

El primer layout (Figura \ref{fig:layout1O}) se basó en la restricción cinemática fundamental del manipulador: su alcance efectivo de 283 mm. Se inscribió un cuadrado dentro del círculo formado por dicho alcance, estableciendo así el área de trabajo primaria donde el robot podría operar con máxima libertad de movimiento.

\begin{figure}[H]
    \centering
    
    \caption{Layout inicial de la plataforma mostrando el cuadrado circunscrito en el área de alcance efectivo del manipulador (radio de 283 mm). Se indica la posición central de la base del manipulador.}
    \label{fig:layout1O}
\end{figure}

\paragraph{Layout Refinado - Sistema de Cuadrícula Modular}

A partir del cuadrado de trabajo definido, se desarrolló un sistema de cuadrícula que sirvió como base dimensional para los módulos cuadrados y rectangulares. En esta segunda iteración del layout (Figura \ref{fig:layout2Obsoleto}), se incorporaron elementos adicionales como:

\begin{itemize}
    \item Ubicación del soporte de cámara en posición superior central
    \item Sistema de anclaje mediante orificios roscados para módulos cuadrados
    \item Sistema de anclaje para módulos rectangulares
    \item Puntos de fijación para canecas de depósito
    \item Zona de montaje de la base del manipulador
\end{itemize}

\begin{figure}[H]
    \centering
    
    \caption{Layout refinado de la plataforma mostrando el sistema de cuadrícula modular. Se identifican los puntos de anclaje para módulos cuadrados (color rojo) y módulos rectangulares (color azul), así como la ubicación del soporte de cámara en la zona superior.}
    \label{fig:layout2Obsoleto}
\end{figure}

Finalmente se repite el patrón en la cuadricula y se obtiene el modelo 3D de la plataforma inicial que se ve en la figura \ref{fig:plataformaBaseV1.0}

\begin{figure}[H]
    \centering
    
    \caption{ Plataforma base version 1.}
    \label{fig:plataformaBaseV1.0}
\end{figure}

\subsubsection{Selección del Material de la Plataforma}

Para la fabricación de la plataforma base se seleccionó tablero de fibra de densidad media (MDF) de 9 mm de espesor. Esta decisión se fundamentó en un análisis comparativo de costos con materiales alternativos.

Si bien el MDF requiere un proceso de acabado superficial que incluye lijado, sellado, pintado y lacado para garantizar durabilidad y resistencia a la humedad, su relación costo-beneficio resultó significativamente superior a otras opciones consideradas.

\begin{table}[H]
\centering
\caption{Comparación de costos de materiales para la plataforma base}
\label{tab:costos_plataforma}
\begin{tabular}{|l|r|r|}
\hline
\textbf{Material} & \textbf{Costo por unidad} & \textbf{Relación de costo} \\
\hline
MDF 9 mm + corte láser & \$25,000 COP & 1.0× (referencia) \\
Acrílico 9 mm + corte láser & \$200,000 COP & 8.0× \\
\hline
\end{tabular}
\end{table}

El acrílico, a pesar de ofrecer ventajas en términos de resistencia a la humedad y acabado superficial, presentó un costo 8 veces superior al MDF. Considerando que se deben fabricar 7 plataformas (una por cada kit), la diferencia total ascendería a \$1,225,000 COP (\$175,000 en MDF vs \$1,400,000 en acrílico), lo cual excede significativamente el presupuesto disponible por kit.

\subsubsection{Problemas Identificados y Rechazo del Diseño}

A pesar del esfuerzo de diseño invertido, esta primera iteración fue rechazada debido a múltiples deficiencias críticas identificadas durante el proceso de evaluación:

\begin{enumerate}
    \item \textbf{Complejidad excesiva del sistema}: El diseño presentaba un número excesivo de partes móviles e interdependientes, lo cual comprometía la robustez y facilidad de uso del kit. El sistema de 178 imanes de neodimio (distribuidos en módulos, zonas de recolección y canecas) representaba:
    \begin{itemize}
        \item Costo elevado en componentes de fijación
        \item Dificultad en el ensamblaje y mantenimiento
        \item Complejidad innecesaria para los objetivos didácticos del kit
    \end{itemize}
    
    \item \textbf{Dimensionamiento inadecuado de la plataforma}: Las dimensiones de ancho y largo de la plataforma no consideraron las tolerancias de fabricación de la canastilla plástica comercial. Las paredes del contenedor pueden presentar cierta flexión debido a su proceso de moldeo por inyección, lo que dificultaba la extracción e inserción de la plataforma. Las holguras previstas (0.5 mm - 3 mm) resultaron insuficientes en la práctica.
    
    \item \textbf{Error fundamental en el análisis cinemático}: Se cometió un error crítico en el proceso de diseño al no considerar adecuadamente las limitaciones cinemáticas del manipulador. El PhantomX Pincher, al poseer únicamente 4 grados de libertad (DOF), presenta restricciones significativas en su capacidad de orientación del efector final. El uso de una cuadrícula regular como layout asumía implícitamente que el robot podría alcanzar cualquier posición con cualquier orientación, lo cual es cinemáticamente incorrecto para un manipulador de 4 DOF.
    
    Esta limitación implicaba que ciertas celdas de la cuadrícula resultarían inaccesibles o accesibles solo con orientaciones específicas del efector final, comprometiendo la funcionalidad del sistema modular propuesto.
    
    \item \textbf{Ausencia de sistema de manipulación}: No se contempló un método ergonómico y práctico para extraer e insertar la plataforma del contenedor. La ausencia de asas, agarraderas o sistemas de sujeción dificultaba el manejo del kit, especialmente considerando el peso combinado de la plataforma, el robot y los componentes electrónicos.
    
    \item \textbf{Omisión del subsistema electrónico}: El diseño no incluyó una ubicación dedicada para los componentes electrónicos del sistema (controlador, fuente de alimentación, cableado). Esta omisión representaba un problema fundamental, ya que la electrónica constituye un elemento esencial del kit que requiere espacio protegido, ventilación adecuada y accesibilidad para mantenimiento.
\end{enumerate}

\subsubsection{Lecciones Aprendidas}

El proceso de diseño y evaluación crítica de esta primera iteración proporcionó valiosas lecciones que orientaron el desarrollo de versiones subsecuentes:

\begin{itemize}
    \item La modularidad excesiva puede comprometer la funcionalidad y aumentar innecesariamente la complejidad
    \item Las restricciones cinemáticas del manipulador deben ser el punto de partida fundamental del diseño, no una consideración posterior
    \item Las tolerancias de fabricación de componentes comerciales deben verificarse mediante prototipos físicos
    \item El diseño debe considerar todos los subsistemas desde las etapas iniciales (mecánico, electrónico, interfaz de usuario)
    \item La simplicidad y robustez son preferibles a la versatilidad cuando esta última compromete la usabilidad
\end{itemize}

Estas observaciones fundamentaron el desarrollo de una segunda iteración del diseño, la cual se presenta en la siguiente sección.

\subsection{Segunda Iteración del Diseño de la Plataforma}

\subsubsection{Principios de Diseño Revisados}

La segunda iteración del diseño incorporó las lecciones aprendidas del primer prototipo, adoptando un enfoque fundamentalmente diferente basado en los siguientes principios rectores:

\begin{enumerate}
    \item \textbf{Eliminación de la modularidad excesiva}: Las zonas de recolección y depósito se diseñaron como elementos fijos, eliminando el sistema de imanes y módulos intercambiables que añadían complejidad innecesaria
    
    \item \textbf{Simplificación del sistema de clasificación}: Se redujo a una única zona de recolección circular y cuatro zonas de depósito de igual área, simplificando la operación y el software de control
    
    \item \textbf{Integración del subsistema electrónico}: Se incorporó desde el inicio un área dedicada para la Raspberry Pi y una zona flexible para componentes electrónicos adicionales
    
    \item \textbf{Consideración de restricciones cinemáticas}: El posicionamiento de las zonas de trabajo se basó en el análisis del alcance efectivo y las limitaciones de 4 DOF del manipulador
    
    \item \textbf{Mejora de la ergonomía}: Se añadieron manijas para facilitar la manipulación de la plataforma
    
    \item \textbf{Estabilidad y nivelación}: Se incorporaron patas niveladoras en las esquinas y patas de soporte centrales para garantizar estabilidad
    
    \item \textbf{Gestión de cableado}: Se diseñaron canaletas específicas para el paso ordenado de cables
    
    \item \textbf{Sistema de vacío}: Se integró el montaje de la bomba de vacío requerida para el nuevo sistema de sujeción
\end{enumerate}

\subsubsection{Arquitectura de Diseño en Dos Niveles}

A diferencia del diseño anterior, esta iteración requirió considerar la plataforma como un sistema de dos niveles funcionales:

\paragraph{Nivel Superior}
Comprende todos los componentes operativos montados sobre la superficie de la plataforma: zonas de trabajo (recolección y depósito), manipulador, sistema de visión, electrónica de control y sistema de vacío.

\paragraph{Nivel Inferior}
Incluye los elementos estructurales y de servicio ubicados en la cara inferior de la plataforma: sistema de cableado, canaletas, tornillería de fijación, patas niveladoras y estructuras de soporte.

Esta arquitectura de dos niveles permite una separación clara entre funcionalidades operativas y de soporte, facilitando el mantenimiento y modificaciones futuras.

\subsubsection{Análisis de Layouts}

El diseño se desarrolló mediante tres layouts complementarios que abordan diferentes aspectos del sistema:

\paragraph{Layout 1: Análisis Cinemático de Zonas de Depósito}

El primer layout (Figura \ref{fig:layout1}) se centra en la validación cinemática de la ubicación de las zonas de depósito. Este análisis demuestra que todas las zonas de depósito se encuentran dentro del alcance efectivo del robot (círculo rojo con radio de 283 mm).

\begin{figure}[H]
    \centering
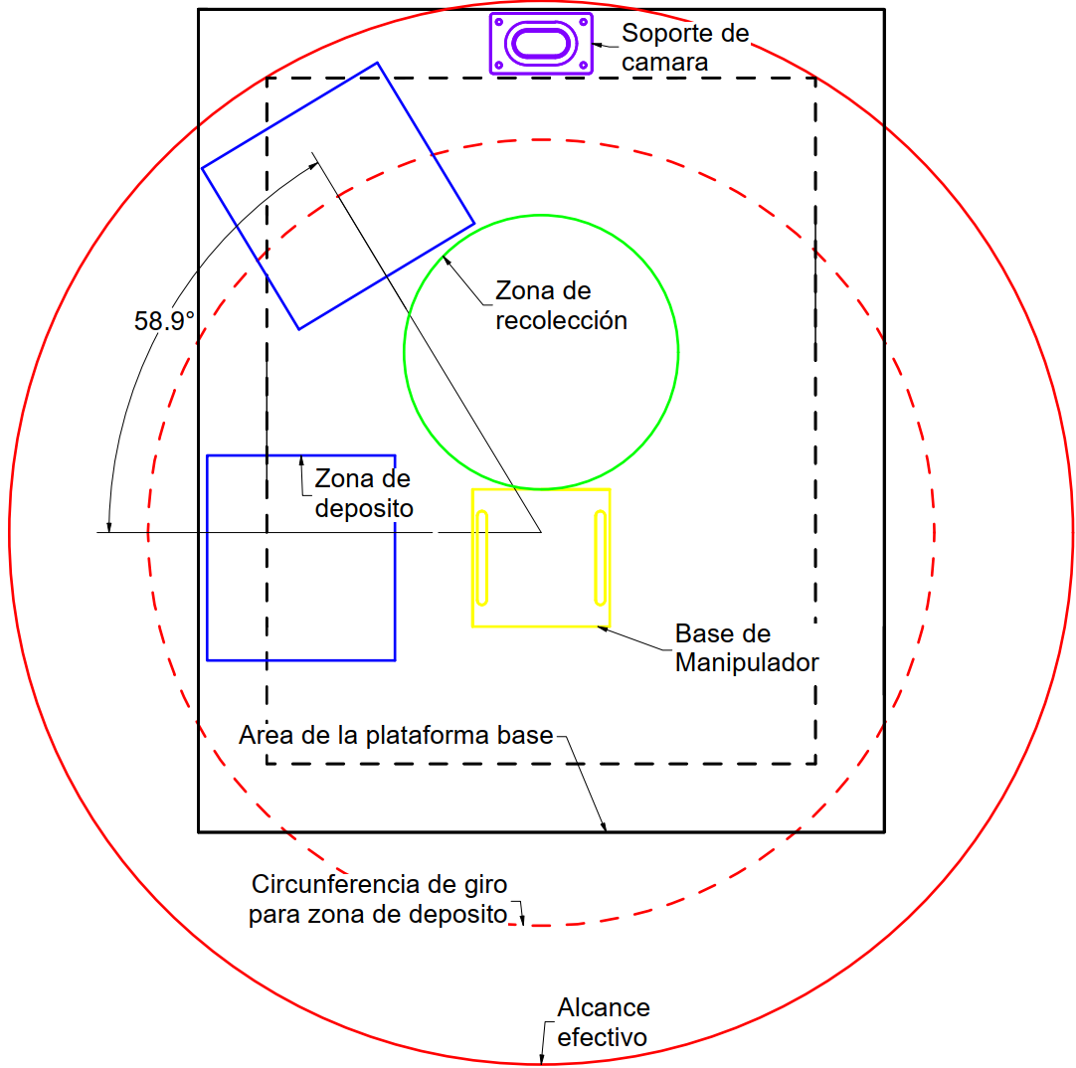
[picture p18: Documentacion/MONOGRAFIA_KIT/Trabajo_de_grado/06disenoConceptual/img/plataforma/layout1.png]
    
    \caption{Layout 1 - Análisis cinemático de accesibilidad. Se muestra cómo las cuatro zonas de depósito (azul) están contenidas dentro del alcance efectivo del manipulador (círculo rojo). El ángulo de 58.9° indica la rotación angular de las zonas de depósito alrededor del eje de la primera articulación del robot, garantizando accesibilidad desde cualquier configuración. La zona de recolección (verde) se ubica en posición central. Se indica también la circunferencia de giro (línea punteada roja) que delimita el área de trabajo óptima.}
    \label{fig:layout1}
\end{figure}

La estrategia de posicionamiento se basó en la rotación de las zonas de depósito alrededor del eje de la primera articulación (base) del robot. Como se observa en la figura, dos de las zonas de depósito se encuentran rotadas 58.9° con respecto al eje longitudinal de la plataforma. Esta disposición angular garantiza que el manipulador, con sus 4 grados de libertad, pueda alcanzar todas las zonas de depósito mediante rotación de su base y movimientos coordinados de sus eslabones, sin requerir orientaciones imposibles del efector final.

\paragraph{Layout 2: Distribución de Componentes en Nivel Superior}

El segundo layout (Figura \ref{fig:layout2}) presenta la distribución completa de componentes en el nivel superior de la plataforma:

\begin{figure}[H]
    \centering
    
    \caption{Layout 2 - Vista superior de la plataforma mostrando la distribución de todos los componentes operativos. Se identifican: zona de electrónica con retícula de montaje (cian), controlador Raspberry Pi (rojo), cuatro zonas de depósito simétricas (azul), zona de recolección central (verde), base del manipulador (amarillo), soporte de cámara (morado), manijas de transporte (rosa), ranuras de cableado (negro) y base de bomba de vacío (naranja). Las dimensiones corresponden a la plataforma de 560 mm × 365 mm.}
    \label{fig:layout2}
\end{figure}

Los elementos clave identificados en este layout son:

\begin{itemize}
    \item \textbf{Zona de electrónica} (cian): Ubicada en la región posterior, más allá del área de trabajo del robot. Incorpora una retícula de montaje flexible de 30 mm × 30 mm
    \item \textbf{Controlador Raspberry Pi} (rojo): Posición dedicada con montaje específico, ubicada lateralmente para facilitar acceso a puertos
    \item \textbf{Zonas de depósito} (azul): Cuatro receptáculos idénticos distribuidos simétricamente alrededor de la zona de recolección
    \item \textbf{Zona de recolección} (verde): Área circular central donde se posicionan los objetos a clasificar
    \item \textbf{Base del manipulador} (amarillo): Montaje central con patrón de tornillería específico para el PhantomX Pincher
    \item \textbf{Soporte de cámara} (morado): Ubicado entre la zona de electrónica y el área de trabajo, proporcionando vista superior de la escena
    \item \textbf{Manijas de transporte} (rosa): Ubicadas en los bordes superior e inferior de la plataforma para facilitar manipulación
    \item \textbf{Ranuras de cableado} (negro): Aberturas estratégicas para paso de cables entre niveles
    \item \textbf{Base de bomba de vacío} (naranja): Montaje cercano a la base del robot para minimizar longitud de mangueras
\end{itemize}

\paragraph{Layout 3: Componentes del Nivel Inferior}

El tercer layout (Figura \ref{fig:layout3}) detalla los elementos estructurales y de servicio ubicados en el nivel inferior de la plataforma:

\begin{figure}[H]
    \centering
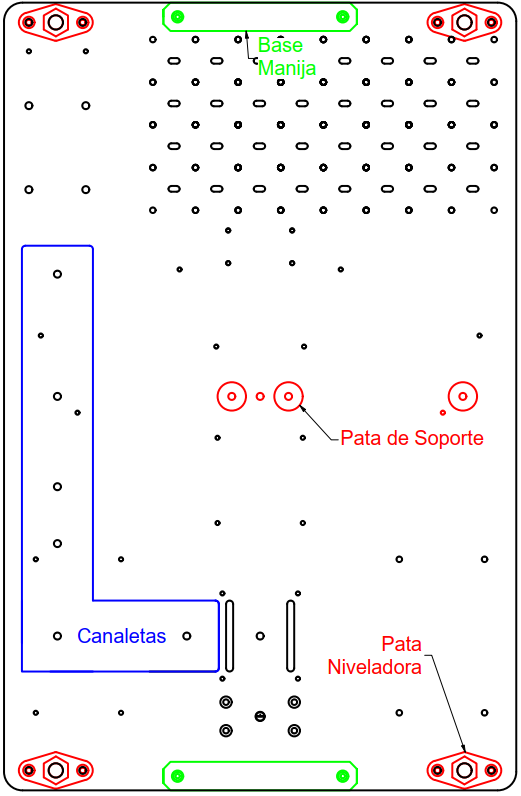
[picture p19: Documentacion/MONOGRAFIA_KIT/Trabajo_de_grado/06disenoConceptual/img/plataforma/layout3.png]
    
    \caption{Layout 3 - Vista inferior de la plataforma mostrando elementos estructurales y de servicio. Se identifican: canaletas de cableado (azul) en forma de L para gestión ordenada de cables, patas niveladoras (rojo) en las cuatro esquinas con roscas M10, patas de soporte centrales (rojo) para rigidez adicional, manijas de transporte (rosa) con tornillería M6, y base de soporte (verde) para fijación del manipulador. El patrón de agujeros permite la instalación de insertos roscados M4 para montaje de componentes.}
    \label{fig:layout3}
\end{figure}

Los componentes del nivel inferior incluyen:

\begin{itemize}
    \item \textbf{Canaletas de cableado} (azul): Configuración en forma de L que permite el ruteo ordenado de cables desde las zonas de depósito y recolección hacia la zona de electrónica
    \item \textbf{Patas niveladoras} (rojo): Ubicadas en las cuatro esquinas, con agujeros roscados M10 que alojan tornillos de nivelación ajustables
    \item \textbf{Patas de soporte centrales} (rojo): Tres puntos de apoyo adicionales que proporcionan rigidez a la plataforma y evitan flexión en la zona central
    \item \textbf{Manijas} (rosa): Montadas con tornillería M6 que atraviesa completamente la plataforma
    \item \textbf{Patrón de insertos roscados}: Distribución de posiciones para insertos de madera roscados M4 que servirán de anclaje para diversos componentes
\end{itemize}

\subsubsection{Estrategia de Posicionamiento de Zonas Funcionales}

\paragraph{Ubicación de Zonas de Depósito}

El posicionamiento de las zonas de depósito se determinó mediante el siguiente proceso:

\begin{enumerate}
    \item Se trazó el círculo de alcance efectivo del robot (radio de 283 mm) centrado en el eje de su primera articulación
    
    \item Se inscribió un cuadrado dentro de este círculo, similar al enfoque del primer diseño
    
    \item Se posicionó una zona de depósito dentro del cuadrado inscrito
    
    \item Esta zona se rotó alrededor del eje de la primera articulación del robot, generando posiciones angulares múltiples
    
    \item Se seleccionaron cuatro posiciones angulares que maximizaban la separación entre zonas mientras mantenían todas las posiciones dentro del alcance efectivo
\end{enumerate}

Esta estrategia garantiza que el manipulador puede alcanzar cualquier zona de depósito mediante una simple rotación de su base, seguida de movimientos coordinados de sus eslabones. La configuración angular de 58.9° entre zonas adyacentes permite una distribución simétrica que facilita la programación del sistema de control.

\paragraph{Zona de Recolección}

La zona de recolección se diseñó como un área circular ubicada en la región central, delimitada por:

\begin{itemize}
    \item Límite interno: Perímetro de la base del brazo robótico
    \item Límite externo: Circunferencia que conecta las zonas de depósito
\end{itemize}

Esta configuración garantiza que cualquier objeto colocado en la zona de recolección es accesible para el manipulador sin interferencias con su propia base o con las zonas de depósito.

\paragraph{Zona de Electrónica}

La zona de electrónica se ubicó estratégicamente más allá del cuadrado circunscrito en el círculo de alcance máximo del robot. Esta ubicación ofrece múltiples ventajas:

\begin{itemize}
    \item Protección física: Los componentes electrónicos quedan fuera del área de movimiento del manipulador, eliminando riesgo de colisiones
    \item Accesibilidad: Posición en el borde de la plataforma facilita conexión y desconexión de cables
    \item Ventilación: Ubicación alejada de componentes mecánicos permite mejor circulación de aire
    \item Expansibilidad: Área suficiente para añadir componentes adicionales según evolucionen los requerimientos
\end{itemize}

\subsubsection{Sistema de Retícula para Montaje Flexible}

La zona de electrónica incorpora un sistema de retícula que proporciona flexibilidad para cambios futuros en los componentes electrónicos del sistema. Esta retícula se compone de:

\paragraph{Patrón de Agujeros Circulares}
Agujeros pasantes de diámetro apropiado para alojar insertos roscados M4, distribuidos en un patrón rectangular con separación de 30 mm entre centros en ambas direcciones. Este espaciado de 30 mm fue seleccionado por:

\begin{itemize}
    \item Compatibilidad con dimensiones estándar de componentes electrónicos y mecánicos
    \item Suficiente densidad de puntos de fijación sin debilitar excesivamente la estructura de MDF
    \item Coincidencia con múltiplos de dimensiones comunes en sistemas robóticos (15 mm, 60 mm, 90 mm)
\end{itemize}

\paragraph{Ranuras de Cableado}
Ranuras oblongas integradas en el patrón de la retícula que permiten el paso de cables entre componentes montados en la superficie y el nivel inferior de la plataforma. Estas ranuras se encuentran estratégicamente ubicadas para:

\begin{itemize}
    \item Permitir conexiones entre la Raspberry Pi y periféricos
    \item Facilitar el paso de mangueras neumáticas si se requiere posicionar la bomba de vacío en la zona de electrónica (configuración alternativa)
    \item Organizar el cableado de alimentación desde fuentes externas
\end{itemize}

\paragraph{Área Dedicada del Controlador}
Además de la retícula general, se diseñó un área específica para el montaje de la Raspberry Pi, con:

\begin{itemize}
    \item Patrón de agujeros coincidente con los puntos de montaje estándar de la Raspberry Pi
    \item Ranuras adyacentes para paso de cables USB, HDMI, y alimentación
    \item Espacio perimetral para acceso a puertos laterales sin remover el controlador
\end{itemize}

La filosofía de diseño de la retícula permite que la electrónica del robot pueda ser actualizada o modificada sin necesidad de rediseñar la plataforma completa, facilitando la evolución del kit según nuevas necesidades educativas o mejoras tecnológicas.

\subsubsection{Sistemas de Fijación y Anclaje}

El diseño contempla múltiples sistemas de anclaje diferenciados según los requerimientos de carga, frecuencia de desmontaje, y tipo de componente:

\paragraph{Anclajes con Insertos Roscados de Madera M4}

Se seleccionaron insertos roscados de madera M4 como sistema de fijación principal para componentes que requieren desmontaje ocasional. Estos insertos se utilizan en:

\begin{itemize}
    \item Soporte de cámara: 4 puntos de fijación
    \item Patas niveladoras: 4 unidades en las esquinas
    \item Patas de soporte central: 3 unidades
    \item Anclaje de bomba de vacío: Configuración según modelo específico
    \item Carcasa del controlador (Raspberry Pi): 4 puntos de montaje
    \item Zonas de recolección: 4 tornillos de fijación
    \item Zonas de depósito: 4 tornillos de fijación cada una (16 tornillos totales)
    \item Base del robot: 4 tornillos de fijación
\end{itemize}

La selección de insertos roscados de madera sobre alternativas convencionales se fundamentó en:

\begin{enumerate}
    \item \textbf{Durabilidad de la rosca}: Los insertos metálicos proporcionan roscas duraderas que no se degradan con ciclos repetidos de montaje/desmontaje, a diferencia de roscas directas en MDF que se desgastan rápidamente
    
    \item \textbf{Facilidad de reemplazo}: Los componentes pueden ser removidos y reinstalados múltiples veces utilizando tornillos estándar M4, sin deterioro del punto de fijación
    
    \item \textbf{Eliminación de tuercas convencionales}: Se evita el uso de tuercas tradicionales que presentan dos problemas principales:
    \begin{itemize}
        \item Susceptibilidad a caerse o perderse durante operaciones de mantenimiento
        \item Tendencia a dañar el acabado superficial (pintura) de la plataforma debido a la presión de apriete concentrada
    \end{itemize}
    
    \item \textbf{Capacidad de carga}: Los insertos M4 proporcionan resistencia adecuada para las cargas presentes en el sistema (peso de componentes y cargas operativas)
\end{enumerate}

\paragraph{Anclaje de Manijas con Tornillería M6}

Las manijas de transporte utilizan tornillos M6 que atraviesan completamente el espesor de la plataforma y se fijan mediante tuercas en el lado inferior. Esta configuración no requiere insertos roscados debido a:

\begin{itemize}
    \item Menor frecuencia de desmontaje (las manijas permanecen instaladas permanentemente)
    \item Mayor área de distribución de carga mediante arandelas de respaldo
    \item Ubicación en los bordes de la plataforma donde el acabado superficial es menos crítico
    \item Requerimiento de mayor resistencia mecánica para soportar el peso completo del kit durante el transporte
\end{itemize}

\paragraph{Sistema de Nivelación con Roscas M10}

Las patas niveladoras requieren agujeros roscados M10 de mayor diámetro. Se utilizan tornillos M10 de cabeza hexagonal o perillas de ajuste manual que funcionan como patas ajustables en altura. Este sistema permite:

\begin{itemize}
    \item Compensar irregularidades de las superficies de trabajo
    \item Ajustar la horizontalidad de la plataforma para operación óptima del manipulador
    \item Proporcionar apoyo estable en las cuatro esquinas
    \item Facilitar ajuste sin herramientas (si se utilizan perillas de ajuste)
\end{itemize}

\subsubsection{Consideraciones de Acabado Superficial}

\paragraph{Selección de Color}

Se seleccionó pintura negra mate como acabado superficial de la plataforma base. Esta decisión se fundamentó en consideraciones de visión por computador:

\begin{enumerate}
    \item \textbf{Contraste cromático}: El fondo negro maximiza el contraste con las zonas de trabajo, que típicamente utilizan colores brillantes (rojo, verde, amarillo, azul) para facilitar su identificación visual
    
    \item \textbf{Facilitación de segmentación}: Los algoritmos de visión por computador basados en umbralización de color o segmentación por espacios de color (HSV, LAB) operan más eficientemente cuando existe alto contraste entre objetos de interés y fondo
    
    \item \textbf{Reducción de reflejos}: El acabado mate minimiza reflejos especulares que pueden interferir con la captura de imágenes, especialmente bajo iluminación artificial del laboratorio
    
    \item \textbf{Uniformidad del fondo}: Un fondo homogéneo negro simplifica el pre-procesamiento de imágenes, reduciendo la carga computacional del sistema de visión
\end{enumerate}

\paragraph{Proceso de Acabado del MDF}

El proceso completo de acabado superficial contempla las siguientes etapas:

\begin{enumerate}
    \item \textbf{Lijado inicial}: Lijado con papel de grano 120-150 para eliminar irregularidades del corte láser
    \item \textbf{Sellado}: Aplicación de sellador para MDF que reduce porosidad y mejora adherencia de la pintura
    \item \textbf{Lijado intermedio}: Lijado con grano 220 después del secado del sellador
    \item \textbf{Aplicación de pintura}: 2-3 capas de pintura negra mate, con lijado suave entre capas
    \item \textbf{Lacado}: Capa final de laca mate transparente para protección contra desgaste y humedad
\end{enumerate}

Este proceso de acabado, aunque laborioso, resulta económicamente viable considerando el ahorro sustancial respecto a materiales alternativos como el acrílico.

\subsubsection{Gestión de Cableado}

El sistema de canaletas en el nivel inferior proporciona rutas dedicadas para diferentes tipos de cables:

\begin{itemize}
    \item \textbf{Cables de potencia}: Desde la fuente de alimentación externa hasta la zona de electrónica
    \item \textbf{Cables de control}: Desde la Raspberry Pi hasta el controlador del manipulador
    \item \textbf{Cables de sensores}: Desde las zonas de trabajo hasta el controlador
    \item \textbf{Cables de comunicación}: Conexiones USB, Ethernet, u otros protocolos de comunicación
    \item \textbf{Mangueras neumáticas}: Desde la bomba de vacío hasta el efector final del manipulador
\end{itemize}

La configuración en forma de L de las canaletas permite una distribución eficiente que minimiza cruces de cables y facilita el mantenimiento.

\subsubsection{Diseño Final de la Plataforma Base}

El diseño final de la plataforma base se presenta en la Figura \ref{fig:plataformaBaseVersionFinal}, donde se observan las dimensiones definitivas y la distribución completa de agujeros y ranuras para el montaje de componentes.

\begin{figure}[H]
    \centering
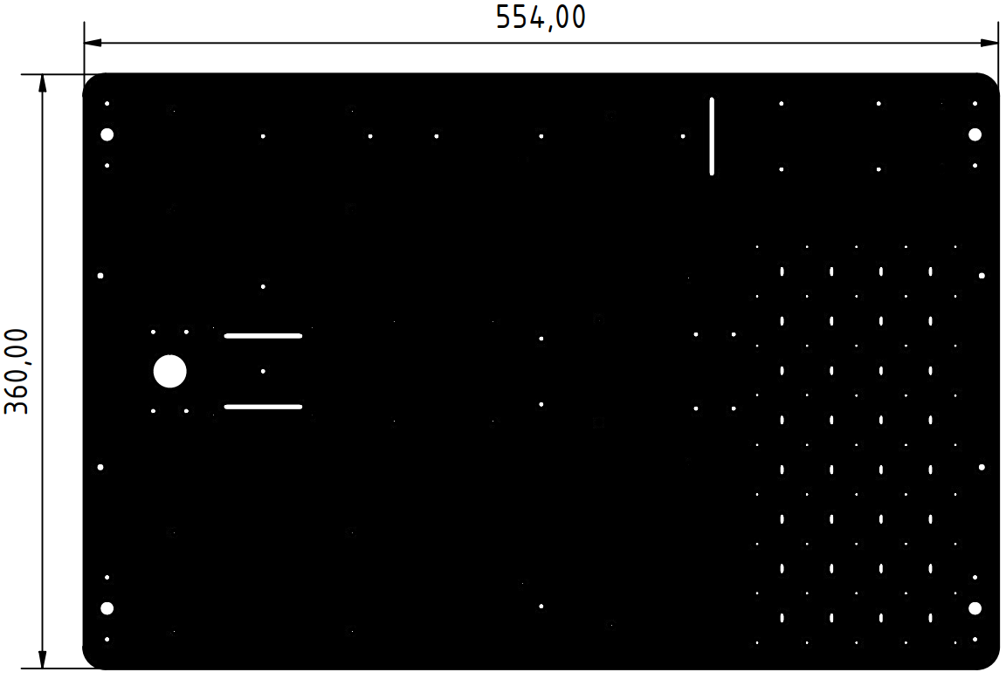
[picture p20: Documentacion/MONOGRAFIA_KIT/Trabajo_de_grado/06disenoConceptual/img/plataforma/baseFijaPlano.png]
    
    \caption{Plano técnico de la plataforma base con dimensiones finales de 554.00 mm × 360.00 mm. Se muestran los agujeros para insertos roscados M4, agujeros para patas niveladoras M10 en las esquinas, ranuras de cableado y la retícula de montaje en la zona de electrónica. El acabado es negro mate para contraste visual.}
    \label{fig:plataformaBaseVersionFinal}
\end{figure}

Las dimensiones finales de la plataforma son 554 mm de largo por 360 mm de ancho, fabricada en MDF de 9 mm de espesor. Estas dimensiones proporcionan holguras de 6 mm y 3 mm con respecto a las dimensiones internas del contenedor (566 mm × 366 mm), facilitando las operaciones de inserción y extracción de la plataforma.

Todos los elementos geométricos mostrados en el plano (agujeros circulares, ranuras oblongas y el perímetro exterior) son completamente realizables mediante corte láser en una única lámina de MDF. El proceso de corte láser garantiza la precisión dimensional necesaria y permite la fabricación repetible de las 7 plataformas requeridas con tolerancias de ±0.1 mm.

Posterior al corte, cada plataforma se somete al proceso de acabado superficial (lijado, sellado, pintado negro mate y lacado) para garantizar durabilidad y proporcionar el contraste visual necesario para los algoritmos de visión por computador.

\subsection{Componentes Estructurales de la Plataforma Base}

La plataforma base integra diversos componentes estructurales diseñados para proporcionar estabilidad, facilitar el transporte y permitir la gestión ordenada del cableado. A continuación se describen estos componentes y sus especificaciones técnicas.

\subsubsection{Patas Niveladoras}

Las patas niveladoras, mostradas en la Figura \ref{fig:pataNiveladora}, permiten ajustar la horizontalidad de la plataforma para compensar irregularidades en las superficies de trabajo. Cada pata niveladora es un subconjunto compuesto por cuatro elementos:

\begin{figure}[H]
    \centering
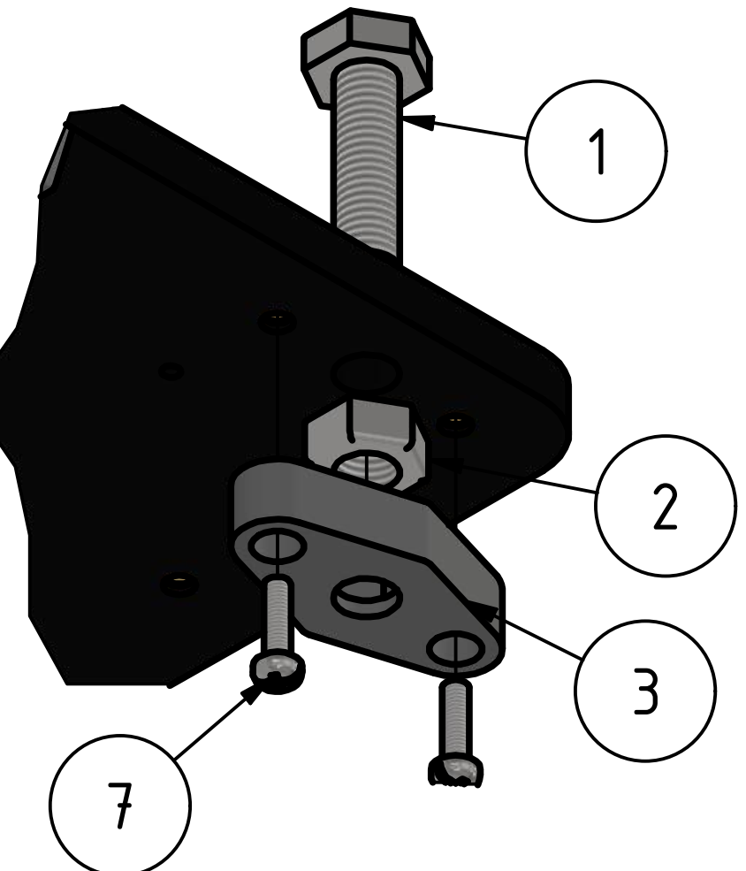
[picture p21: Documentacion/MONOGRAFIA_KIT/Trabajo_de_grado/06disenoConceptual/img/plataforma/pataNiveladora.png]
    
    \caption{Ensamble de pata niveladora. (1) Tornillo M10 × 35 mm que funciona como elemento de ajuste de altura, (2) Acople impreso en 3D con cavidad hexagonal para alojar la tuerca M10.}
    \label{fig:pataNiveladora}
\end{figure}
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

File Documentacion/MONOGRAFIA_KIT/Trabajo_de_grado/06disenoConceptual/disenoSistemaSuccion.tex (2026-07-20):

\subsection{Diseño del Sistema de Succión con Ventosa}

El sistema de efector final del kit incorpora un mecanismo de succión por vacío como alternativa al gripper mecánico original del PhantomX Pincher. Este sistema permite la manipulación de objetos ligeros mediante adhesión neumática, ampliando las capacidades didácticas del kit.

\subsubsection{Condiciones de Diseño}

Las restricciones y requerimientos técnicos del sistema de succión son:

\begin{itemize}
    \item Voltaje de alimentación disponible: 12 V DC (fuente del robot)
    \item Área típica de objetos a manipular: 25 mm × 25 mm
    \item Diámetro de ventosa seleccionada: 15 mm
    \item Restricción espacial: La bomba debe caber dentro de la base del manipulador
    \item Compatibilidad neumática: Conexión a mangueras de 6 mm de diámetro
\end{itemize}

\subsubsection{Evaluación de Bombas de Vacío}
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

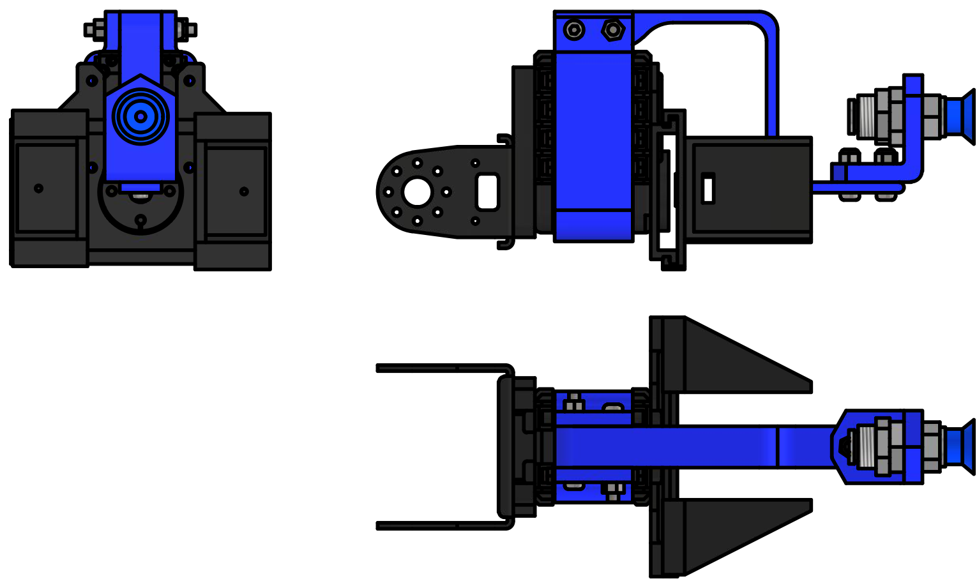
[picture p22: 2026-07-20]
Documentacion/MONOGRAFIA_KIT/Trabajo_de_grado/06disenoConceptual/img/succion/vistasVentosa.png

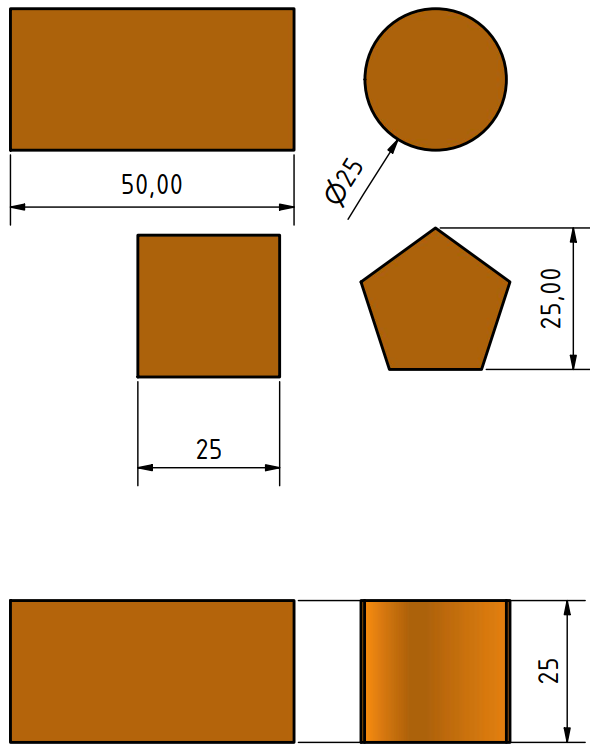
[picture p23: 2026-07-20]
Documentacion/MONOGRAFIA_KIT/Trabajo_de_grado/06disenoConceptual/img/zonaRecoleccion/objetosRecoleccion.png

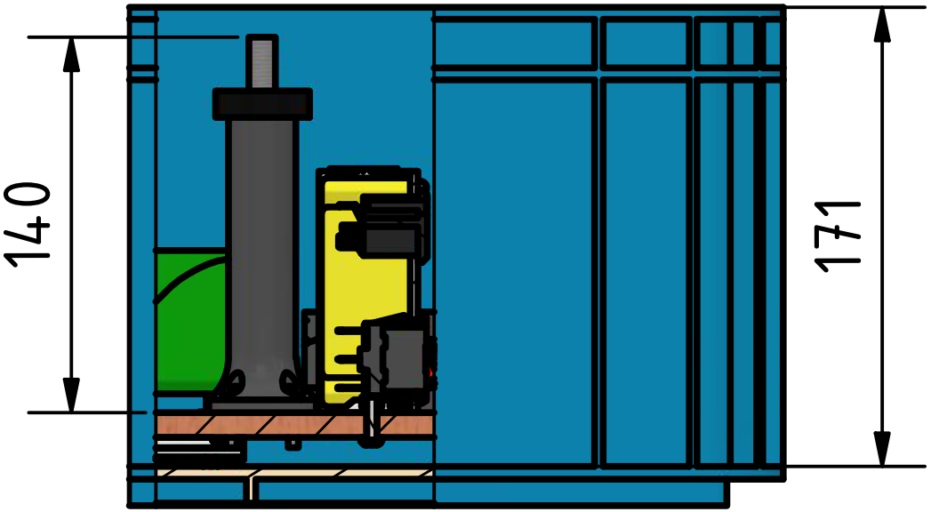
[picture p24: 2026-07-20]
Documentacion/MONOGRAFIA_KIT/Trabajo_de_grado/06disenoConceptual/img/camara/vistaInternaKitBaseMastil.png

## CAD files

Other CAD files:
Kit/STLS/tubosOvaladosNiquel/ensambleSoporteCamara.stl
Kit/tubosOvaladosNiquel/soporteCamara/ensambleSoporteCamara.stl
Kit/Plaquitas/letreros/unpxp5.stl
Kit/STLS/Carcasa/canastilla.stl
Kit/STLS/cases/caseRaspberryPi5/slidePi5/baseCaseRaspberry.stl
Kit/STLS/cases/caseRaspberryPi5/turtleCasePi5/tapaTurtleCase.stl
Kit/STLS/objetosRecoleccion/rectangulo.stl
Kit/STLS/suctionCupGripper/succionGripperFixed/extensionGripper.stl
Kit/STLS/suctionCupGripper/topeDerechoSuctionCup.stl
Kit/Plaquitas/letreros/unpxp2.stl
Kit/STLS/cases/caseRaspberryPi5/slidePi5/tapaSlide.stl
Kit/STLS/cases/caseRaspberryPi5/turtleCasePi5/baseTurtleCase.stl
Kit/STLS/objetosRecoleccion/cubo25x25.stl
Kit/STLS/suctionCupGripper/succionGripperFixed/anclajeGripper.stl
Kit/STLS/suctionCupGripper/suctionCupGripper.stl
Kit/STLS/tubosOvaladosNiquel/vigaSoporteCamara.stl
Kit/Plaquitas/letreros/unpxp3.stl
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

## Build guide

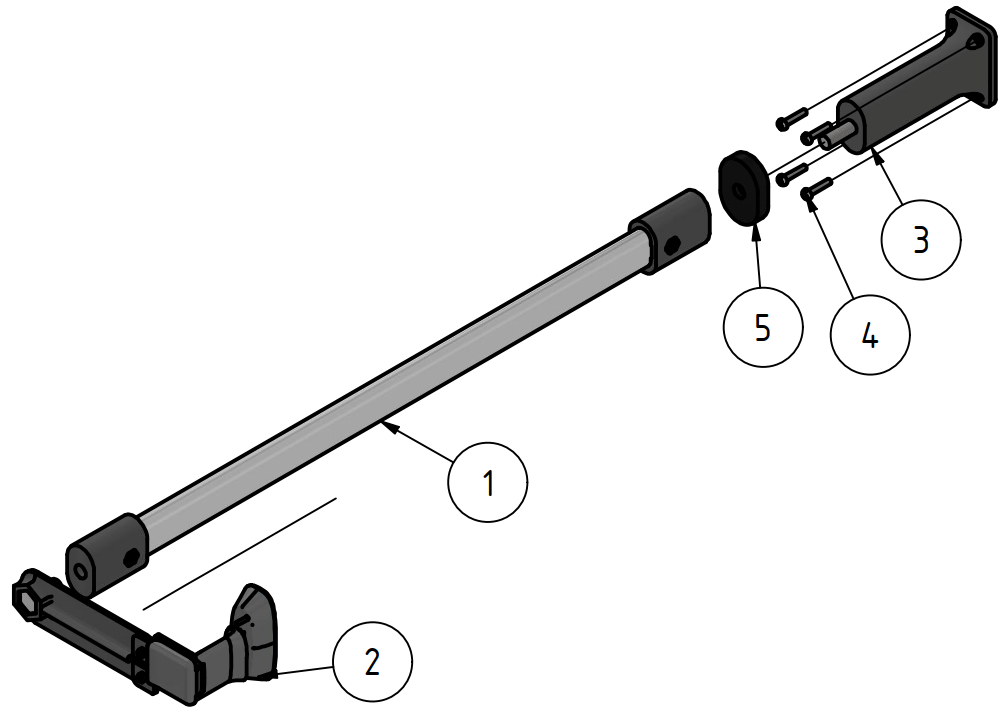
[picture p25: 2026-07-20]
Documentacion/MONOGRAFIA_KIT/Trabajo_de_grado/06disenoConceptual/img/camara/ensambleSoporteCamara.png

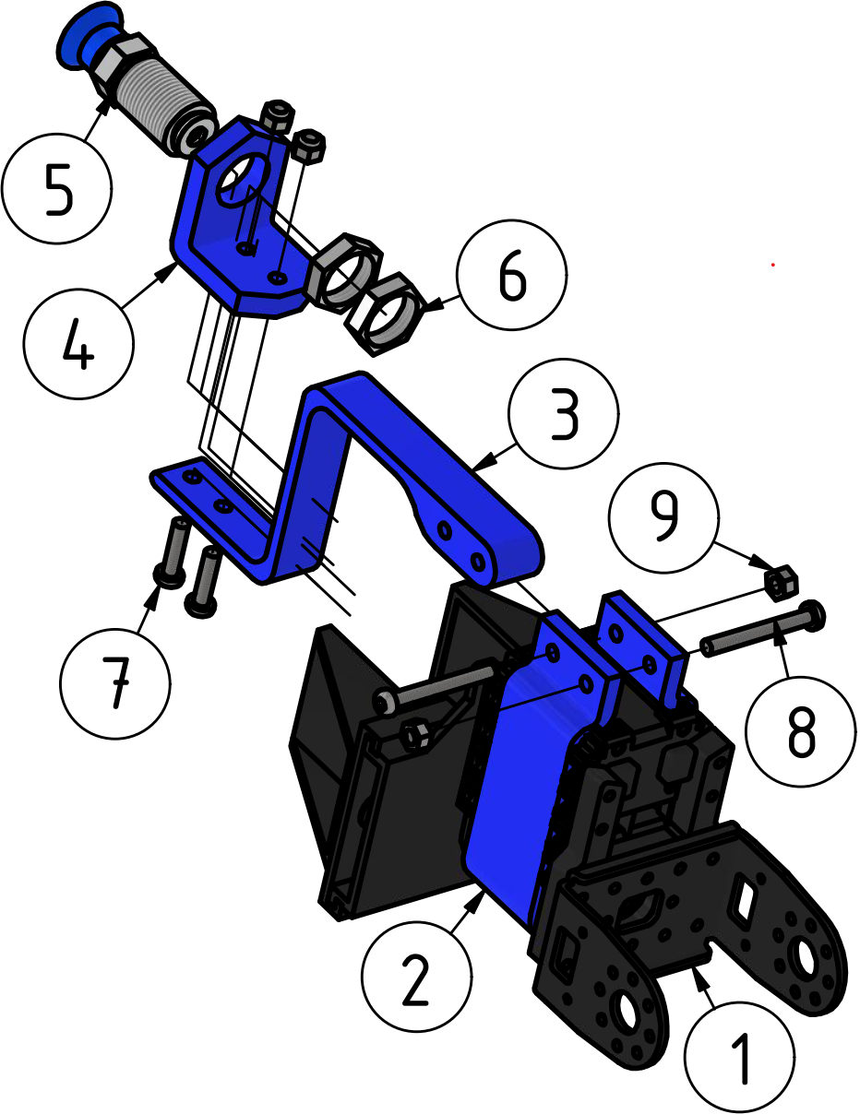
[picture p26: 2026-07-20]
Documentacion/MONOGRAFIA_KIT/Trabajo_de_grado/06disenoConceptual/img/succion/ensambleVentosa.png

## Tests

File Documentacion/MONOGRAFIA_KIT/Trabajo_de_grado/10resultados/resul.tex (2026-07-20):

Este capítulo presenta los resultados obtenidos en el desarrollo del kit educativo de clasificación de objetos con visión por computador para el robot PhantomX Pincher. Los resultados se organizan siguiendo la estructura de objetivos específicos planteados, abordando aspectos de hardware, software, diseño mecánico, simulación, implementación educativa y construcción de prototipos físicos.

%==============================================================================
\section{Selección de Hardware y Software}
%==============================================================================

En respuesta al objetivo específico de identificar los requerimientos de hardware y software necesarios para el sistema de clasificación, se realizó un proceso de evaluación comparativa que culminó en la selección de componentes óptimos para la plataforma educativa.

\subsection{Plataforma de Procesamiento}

Se identificó la \textbf{Raspberry Pi 5 con 16 GB de RAM} como la plataforma de procesamiento óptima para los kits educativos. Esta selección se fundamentó en los siguientes criterios técnicos:

\begin{itemize}
    \item \textbf{Rendimiento computacional}: El procesador Broadcom BCM2712 de cuatro núcleos Cortex-A76 a 2.4 GHz proporciona capacidad suficiente para ejecutar simultáneamente ROS2 Jazzy, MoveIt2, procesamiento de imágenes con OpenCV y controladores de hardware en tiempo real.
    
    \item \textbf{Memoria RAM}: Los 16 GB de RAM permiten operación fluida del sistema sin degradación de rendimiento durante tareas de planificación de trayectorias complejas y procesamiento de imágenes en resolución 1280×720 píxeles a 30 fps.
    
    \item \textbf{Compatibilidad con ROS2}: Soporte nativo para Ubuntu 24.04 LTS (arquitectura ARM64), sistema operativo base para ROS2 Jazzy utilizado en el desarrollo del workspace.
    
    \item \textbf{Conectividad}: Interfaz GPIO de 40 pines para control de actuadores, 2 puertos USB 3.0 para cámara y periféricos, puerto Ethernet Gigabit para transferencia de datos y depuración remota.
    
    \item \textbf{Relación costo-beneficio}: Precio competitivo en comparación con computadores de placa única de prestaciones equivalentes, alineado con restricciones presupuestarias para producción de múltiples unidades.
\end{itemize}

\subsection{Stack de Software}

El stack de software seleccionado integra las siguientes tecnologías:

\begin{itemize}
    \item \textbf{Sistema operativo}: Ubuntu 24.04 LTS Server (64-bit) optimizado para operación en Raspberry Pi 5
    \item \textbf{Framework robótico}: ROS2 Jazzy Jalisco (distribución LTS con soporte hasta 2029)
    \item \textbf{Planificación de movimiento}: MoveIt2 con planificadores OMPL (RRTConnect, RRTstar, PRM)
    \item \textbf{Visión por computador}: OpenCV 4.8 con bindings Python para procesamiento de imágenes
    \item \textbf{Control de hardware}: Dynamixel SDK para comunicación con servomotores AX-12A mediante protocolo serie
    \item \textbf{Simulación física}: Gazebo Harmonic integrado con ROS2 para validación previa a despliegue en hardware real
\end{itemize}

Esta configuración de software proporciona un entorno completo para desarrollo, simulación y operación del sistema de clasificación, cumpliendo con estándares industriales y académicos actuales en robótica de servicio.

%==============================================================================
\section{Diseño Mecánico y Modelado 3D}
%==============================================================================

En concordancia con el objetivo de diseñar conceptualmente la estructura física del kit, se desarrolló un sistema mecánico completo que integra todos los componentes operativos y de almacenamiento. El diseño se materializó mediante modelado tridimensional en SolidWorks 2023, generando geometrías optimizadas para fabricación mediante manufactura aditiva (FDM) y mecanizado de tableros MDF.

\subsection{Componentes Desarrollados}

El proceso de diseño resultó en la generación de modelos 3D para los siguientes componentes:

\subsubsection{Plataforma Base}

Estructura principal fabricada en tablero MDF de 9 mm de espesor con dimensiones finales de 554 mm × 360 mm × 706 mm (incluyendo mástil de cámara). La plataforma integra:

\begin{itemize}
    \item Sistema de retícula de montaje con insertos roscados M4 para fijación de componentes
    \item Cuatro patas niveladoras ajustables mediante tornillos M10 en las esquinas
    \item Patas de soporte centrales para rigidez estructural adicional
    \item Dos manijas de transporte laterales con tornillería M6
    \item Canaletas de gestión de cableado con tapas transparentes en PETG
\end{itemize}

\subsubsection{Zonas de Trabajo}

\begin{itemize}
    \item \textbf{Zona de recolección}: Disco circular de Ø146 mm fabricado en PLA blanco, fijado mediante cuatro tornillos M3 a insertos roscados de la plataforma. Posicionado en el centro del área de alcance efectivo del manipulador.
    
    \item \textbf{Zonas de depósito}: Cuatro canecas con dimensiones externas de 100 mm × 94 mm y profundidad útil de 142 mm. Cada caneca incorpora tapa deslizante accionada manualmente, insertos roscados M3 de latón instalados térmicamente, y sistema de separadores de altura para montaje elevado.
\end{itemize}

\subsubsection{Base del Manipulador}

Soporte estructural para el robot PhantomX Pincher que reemplaza la base original de acrílico. El diseño incorpora identificación numérica grabada para gestión de inventario en entornos de laboratorio con múltiples unidades.

\subsubsection{Soporte de Cámara}

Estructura modular compuesta por:
\begin{itemize}
    \item Mástil vertical de 280 mm de altura fabricado mediante FDM
    \item Brazo voladizo de 200 mm con inclinación de 15° para orientación óptima de la cámara
    \item Soporte de montaje para cámara Logitech C270 con ajuste de inclinación
    \item Sistema de fijación mediante tornillos M4 a insertos roscados de la plataforma
\end{itemize}

\subsubsection{Sistema de Alimentación Eléctrica}

Regleta de distribución personalizada que integra:
\begin{itemize}
    \item Cuatro salidas AC 110V con fusible de protección de 15A
    \item Tres interruptores individuales para control independiente de subsistemas (manipulador, controlador, bomba de vacío)
    \item Carcasa impresa en 3D con cavidades para alojamiento de componentes eléctricos
    \item Cable de alimentación principal con conector tipo NEMA 5-15P
\end{itemize}

\subsection{Documentación de Diseño}

Como resultado del proceso de modelado, se generó documentación técnica completa que incluye:

\begin{itemize}
    \item \textbf{Modelos CAD nativos}: Archivos fuente en formato SolidWorks (.SLDPRT, .SLDASM) con árbol de características editables
    \item \textbf{Geometrías de manufactura}: Exportación de 127 archivos STL optimizados para impresión 3D con orientación de capa óptima
    \item \textbf{Planos técnicos}: Documentación de 15 componentes críticos con acotación completa, tolerancias dimensionales y especificaciones de material
    \item \textbf{Ensambles}: 8 subensambles documentados con explosionados, listas de materiales (BOM) y secuencias de montaje
    \item \textbf{Esquemas eléctricos}: Diagramas de conexión para sistema de distribución eléctrica, interfaz de control y cableado de señal
\end{itemize}

Esta documentación se organizó en repositorio Git estructurado con las siguientes carpetas:

\begin{itemize}
    \item \texttt{CAD/}: Modelos nativos SolidWorks organizados por subsistema
    \item \texttt{STL/}: Archivos de manufactura listos para impresión 3D
    \item \texttt{Planos/}: Documentación técnica en formato PDF
    \item \texttt{Electronica/}: Esquemas de circuitos y listas de componentes
    \item \texttt{Ensambles/}: Instrucciones de montaje ilustradas
\end{itemize}

El repositorio completo se entregó como parte de los entregables del proyecto, permitiendo reproducción, modificación y extensión del diseño por parte de instituciones educativas que adopten el kit.

%==============================================================================
\section{Arquitectura de Software y Simulación}
%==============================================================================

Dando respuesta a los objetivos de proponer una arquitectura de software basada en ROS2 y desarrollar simulaciones compatibles, se implementó un workspace completo que integra descripción del robot, planificación de movimiento, control de hardware y capacidades de visión artificial.

\subsection{Estructura del Workspace ROS2}

El workspace \texttt{phantom\_ws} se estructuró siguiendo convenciones estándar de ROS2, resultando en 9 paquetes especializados:

\begin{itemize}
    \item \textbf{phantomx\_pincher\_description}: Modelos URDF/SDF del robot con parámetros configurables mediante Xacro, mallas visuales y de colisión, definición de marcos de referencia (TF tree)
    
    \item \textbf{phantomx\_pincher\_moveit\_config}: Configuración completa de MoveIt2 incluyendo SRDF (definición de grupos de planificación, estados nombrados), parámetros de cinemática, configuración de planificadores OMPL, límites de articulaciones
    
    \item \textbf{phantomx\_pincher\_bringup}: Archivos launch jerárquicos para arranque del sistema en diferentes modos (simulación fake, Gazebo, hardware real), configuración condicional de nodos
    
    \item \textbf{phantomx\_pincher\_commander\_cpp}: Interfaz de alto nivel en C++ para envío de comandos de movimiento, wrapper de MoveGroupInterface de MoveIt2
    
    \item \textbf{phantomx\_pincher\_demos}: Scripts de demostración en Python para operaciones básicas (objetivos de articulación, objetivos de pose cartesiana, rutinas pick-and-place)
    
    \item \textbf{phantomx\_pincher\_opencv}: Nodos de visión por computador para captura de cámara, procesamiento de imágenes, detección de figuras geométricas
    
    \item \textbf{phantomx\_pincher\_interfaces}: Definición de mensajes personalizados (PoseCommand, VisionResult) y servicios para comunicación entre nodos
    
    \item \textbf{pincher\_control}: Controladores de hardware para comunicación con servomotores Dynamixel mediante protocolo serie, implementación de interfaces ros2\_control
    
    \item \textbf{phantomx\_pincher} (metapaquete): Dependencias y configuración global del workspace
\end{itemize}

\subsection{Capacidades de Simulación}

El workspace implementa tres modos de operación con simulación progresiva:

\begin{enumerate}
    \item \textbf{Modo fake (controladores simulados)}: Ejecución de planificación y visualización sin física simulada, útil para validación rápida de cinemática y algoritmos de planificación
    
    \item \textbf{Modo Gazebo}: Simulación física completa con modelo dinámico del manipulador, detección de colisiones, visualización realista en entorno 3D
    
    \item \textbf{Modo hardware real}: Operación con robot físico, transición directa desde simulación sin modificación de código de alto nivel
\end{enumerate}

La arquitectura permite conmutar entre modos mediante argumentos de launch, facilitando flujo de desarrollo: validación en fake → pruebas en Gazebo → despliegue en hardware.

\subsection{Flujo de Datos del Sistema}

Se implementó pipeline de procesamiento con la siguiente arquitectura de nodos:

\begin{itemize}
    \item \textbf{Nodo de visión}: Captura frames de cámara (1280×720 @ 30 fps), conversión RGB→HSV, segmentación por color, detección de contornos, clasificación de figuras, publicación en tópico \texttt{/tipo\_figura}
    
    \item \textbf{Nodo clasificador}: Suscripción a \texttt{/tipo\_figura}, mapeo de figura a coordenadas de caneca, generación de secuencia de movimientos (8 pasos), publicación de comandos a MoveIt2
    
    \item \textbf{Nodo de planificación (MoveIt2)}: Recepción de objetivos de pose, planificación de trayectorias libres de colisión con OMPL, ejecución mediante controladores
    
    \item \textbf{Nodo de control}: Interfaz con hardware (fake/Gazebo/real), actualización de estados de articulaciones a 250 Hz, publicación en \texttt{/joint\_states}
    
    \item \textbf{Robot State Publisher}: Cálculo de transformadas geométricas (árbol TF), publicación para visualización en RViz
\end{itemize}

Esta arquitectura modular permite desarrollo independiente de componentes, facilitando extensión y mantenimiento del sistema.

\subsection{Material de Apoyo Educativo}

Como parte del entregable de software, se desarrollaron guías técnicas documentadas en formato Markdown:

\begin{itemize}
    \item \textbf{Setup}: Instrucciones completas de instalación de ROS2 Jazzy, dependencias del sistema, configuración de workspace, compilación de paquetes
    
    \item \textbf{MoveIt}: Tutorial de uso de Motion Planning Plugin en RViz, definición de rutinas de clasificación, análisis de trayectorias
    
    \item \textbf{Proyecto}: Rúbrica de evaluación para implementación educativa, lista de verificación de entregables, criterios de calificación cuantitativos
\end{itemize}

Adicionalmente, se proporcionan scripts de demostración ejecutables que ilustran casos de uso fundamentales del sistema.

%==============================================================================
\section{Implementación Física del Kit}
%==============================================================================

En cumplimiento del objetivo de construir prototipos físicos del kit de clasificación, se fabricaron y ensamblaron \textbf{7 unidades completas} del sistema. La producción se realizó en instalaciones del Departamento de Ingeniería Mecánica y Mecatrónica, empleando técnicas de manufactura aditiva (impresión 3D FDM) y mecanizado convencional (corte de MDF con router CNC).

\subsection{Configuración de Kits Entregados}

La entrega de las 7 unidades se distribuyó en tres configuraciones diferenciadas según disponibilidad de componentes:

\begin{table}[H]
\centering
\caption{Distribución de configuraciones de kits entregados}
\label{tab:kits_entregados}
\begin{tabular}{|l|c|c|c|c|}
\hline
\textbf{Configuración} & \textbf{Cantidad} & \textbf{Robot} & \textbf{Raspberry Pi 5} & \textbf{Estado} \\
\hline
Completa & 2 & PhantomX Pincher & RPi 5 16GB & Operativo \\
\hline
Sin controlador & 3 & PhantomX Pincher & --- & Requiere RPi \\
\hline
Sin robot & 2 & --- & RPi 5 16GB & Requiere robot \\
\hline
\textbf{Total} & \textbf{7} & \textbf{5} & \textbf{5} & --- \\
\hline
\end{tabular}
\end{table}

\textbf{Justificación de configuraciones parciales}:

\begin{itemize}
    \item \textbf{Kits sin robot (2 unidades)}: Limitaciones de disponibilidad del manipulador PhantomX Pincher en proveedores nacionales al momento de la fabricación. Estos kits se entregan con todos los componentes mecánicos, electrónicos y de control, permitiendo integración posterior del robot cuando esté disponible sin modificaciones adicionales al sistema.
    
    \item \textbf{Kits sin Raspberry Pi (3 unidades)}: Restricciones presupuestarias para adquisición de 7 unidades de Raspberry Pi 5 con 16 GB de RAM. Los kits incluyen robot PhantomX Pincher instalado y todos los componentes mecánicos, requiriendo únicamente incorporación del controlador para operación completa.
    
    \item \textbf{Kits completos (2 unidades)}: Sistemas totalmente funcionales utilizados para validación de operación, generación de material fotográfico/audiovisual de demostración, y disponibilidad inmediata para inicio de actividades educativas.
\end{itemize}

Esta estrategia de entrega escalonada permite a la institución iniciar actividades con los 2 kits completos mientras gestiona adquisición de componentes faltantes para completar las 5 unidades restantes, maximizando aprovechamiento de la inversión realizada.

\subsection{Componentes Comunes a Todos los Kits}

Independientemente de la configuración, las 7 unidades incluyen:

\begin{itemize}
    \item Plataforma base en MDF con acabado negro mate (554 × 360 mm)
    \item Sistema completo de zonas de trabajo (4 canecas con tapas deslizantes + zona de recolección)
    \item Soporte de cámara con mástil vertical y brazo voladizo
    \item Base del manipulador con identificación numérica
    \item Regleta de distribución eléctrica personalizada con 3 interruptores independientes
    \item Sistema de canaletas de gestión de cableado con tapas transparentes
    \item Patas niveladoras ajustables y manijas de transporte
    \item Contenedor de almacenamiento y transporte (600 × 400 × 171 mm)
\end{itemize}

\subsection{Proceso de Manufactura}

La fabricación de componentes se realizó mediante los siguientes procesos:

\begin{itemize}
    \item \textbf{Impresión 3D FDM}: 127 piezas únicas fabricadas en PLA, PETG y TPU. Parámetros de impresión: altura de capa 0.2 mm, relleno 20-40\% según función estructural, temperatura de extrusión 200-230°C según material. Tiempo total de impresión: aproximadamente 280 horas distribuidas en 4 impresoras Ender 3 S1 Pro.
    
    \item \textbf{Mecanizado CNC}: 7 plataformas base cortadas en tablero MDF de 9 mm mediante router CNC. Perforaciones de Ø5 mm para insertos roscados ejecutadas con precisión de ±0.1 mm. Acabado superficial con pintura en aerosol negro mate aplicada en 3 capas.
    
    \item \textbf{Instalación de insertos}: 280 insertos roscados de latón (M3 y M4) instalados térmicamente mediante cautín a temperatura controlada (350°C). Profundidad de instalación verificada con pie de rey digital.
    
    \item \textbf{Ensamble final}: Montaje de componentes siguiendo secuencia documentada en manuales de ensamble. Verificación de funcionalidad mecánica (niveles de plataforma, deslizamiento de tapas, apertura de canaletas).
\end{itemize}

\subsection{Control de Calidad}

Cada kit fabricado pasó por proceso de verificación que incluye:

\begin{itemize}
    \item Inspección dimensional de componentes críticos (±0.5 mm tolerancia)
    \item Prueba de rigidez estructural de plataforma (carga vertical de 10 kg sin deflexión >2 mm)
    \item Verificación de ajuste de piezas ensambladas (ausencia de holguras excesivas)
    \item Prueba de continuidad eléctrica en sistema de distribución de potencia
    \item Validación de accesibilidad del manipulador a las 4 zonas de depósito (kits con robot instalado)
\end{itemize}

%==============================================================================
\section{Entregables Digitales}
%==============================================================================

Como complemento a los kits físicos, se generaron tres repositorios digitales que constituyen la base de conocimiento transferible para reproducción, extensión y mantenimiento del sistema. Los repositorios se encuentran alojados en la organización GitHub del Laboratorio de Sistemas Inteligentes y Robótica (LabSIR) de la Universidad Nacional de Colombia, garantizando acceso público permanente y control de versiones mediante Git.

\begin{table}[H]
\centering
\caption{Repositorios digitales del proyecto}
\label{tab:repositorios}
\small
\begin{tabular}{|l|p{6cm}|p{5.5cm}|}
\hline
\textbf{Repositorio} & \textbf{Contenido} & \textbf{URL} \\
\hline
Software ROS2 & Workspace completo con 9 paquetes, guías educativas y scripts de demostración & \url{github.com/labsir-un/KIT_Phantom_X_Pincher_ROS2} \\
\hline
Imagen SO & Backup completo de Raspberry Pi 5 con Ubuntu 24.04 LTS y ROS2 Jazzy preconfigurado & \url{github.com/labsir-un/UNPi5_Image_Ubuntu24_04} \\
\hline
Modelos 3D & Archivos CAD, geometrías STL, planos técnicos y esquemas eléctricos & \url{github.com/labsir-un/3DModels_KIT_Phantom_Pincher_X100} \\
\hline
\end{tabular}
\end{table}

\subsection{Repositorio de Imagen del Sistema Operativo}

Se desarrolló imagen completa del sistema operativo configurado para Raspberry Pi 5, lista para despliegue en hardware mediante escritura directa a tarjeta microSD. La imagen incluye:

\begin{itemize}
    \item \textbf{Sistema base}: Ubuntu 24.04 LTS Server (64-bit) con kernel optimizado para ARM64
    \item \textbf{ROS2 Jazzy}: Instalación completa de distribución Desktop con todos los paquetes base
    \item \textbf{Dependencias compiladas}: MoveIt2, ros2\_control, Gazebo Harmonic, OpenCV 4.8 con bindings Python
    \item \textbf{Workspace precompilado}: \texttt{phantom\_ws} con todos los paquetes construidos y configurados
    \item \textbf{Scripts de inicialización}: Archivos systemd para arranque automático de nodos al encendido
    \item \textbf{Configuración de red}: Interfaces Ethernet y WiFi preconfiguradas con IP estática para acceso remoto
    \item \textbf{Herramientas de desarrollo}: Visual Studio Code, Git, tmux, htop para desarrollo y depuración
\end{itemize}

\textbf{Especificaciones técnicas del backup}:
\begin{itemize}
    \item Formato: Imagen raw comprimida con gzip (.img.gz)
    \item Tamaño: 8.2 GB comprimido, 32 GB descomprimido
    \item Hash SHA256: Incluido para verificación de integridad
    \item Repositorio: \url{https://github.com/labsir-un/UNPi5_Image_Ubuntu24_04}
    \item Instrucciones: Documentación paso a paso para restauración en nueva tarjeta microSD
\end{itemize}

Este backup elimina proceso de configuración inicial (instalación de ROS2, compilación de workspace, configuración de permisos), reduciendo tiempo de puesta en marcha de aproximadamente 6 horas a 30 minutos (tiempo de escritura de imagen).

\subsection{Repositorio de Modelado 3D y Electrónica}

Repositorio Git estructurado con versionamiento completo de archivos CAD, geometrías de manufactura y documentación técnica. Organización:

\begin{verbatim}
kit-phantomx-hardware/
|-- CAD/
|   |-- Plataforma_Base/
|   |-- Zonas_Trabajo/
|   |-- Soporte_Camara/
|   |-- Sistema_Electrico/
|   +-- Ensamble_General/
|-- STL/
|   |-- Componentes_Estructurales/
|   |-- Elementos_Funcionales/
|   +-- Accesorios/
|-- Planos/
|   |-- Plataforma_Base.PDF
|   |-- Canecas_Deposito.PDF
|   +-- (15 planos tecnicos totales)
|-- Electronica/
|   |-- Esquematicos/
|   |-- Lista_Componentes.xlsx
|   +-- Diagramas_Conexion/
+-- README.md
\end{verbatim}

El repositorio completo de hardware se encuentra disponible en: \url{https://github.com/labsir-un/3DModels_KIT_Phantom_Pincher_X100}

\textbf{Contenido cuantificado}:
\begin{itemize}
    \item 142 archivos CAD nativos (.SLDPRT, .SLDASM)
    \item 127 archivos STL listos para impresión 3D
    \item 15 planos técnicos en formato PDF con acotación completa
    \item 8 esquemas eléctricos en formato editable
    \item 3 listas de materiales (BOM) en formato Excel
\end{itemize}

\subsection{Repositorio de Software ROS2}

Workspace completo con código fuente, configuraciones, simulaciones y material educativo. Estructura:

\begin{verbatim}
phantom_ws/
|-- src/
|   |-- phantomx_pincher_description/
|   |-- phantomx_pincher_moveit_config/
|   |-- phantomx_pincher_bringup/
|   |-- phantomx_pincher_commander_cpp/
|   |-- phantomx_pincher_demos/
|   |-- phantomx_pincher_opencv/
|   |-- phantomx_pincher_interfaces/
|   |-- pincher_control/
|   +-- phantomx_pincher/
|-- guias/
|   |-- Setup/
|   |   |-- readme.md
|   |   +-- setupOpenCV/
|   |-- Moveit/
|   |   +-- readme.md
|   +-- Proyecto/
|       +-- readme.md (rubrica de evaluacion)
+-- README.md
\end{verbatim}

El workspace completo de software se encuentra disponible en: \url{https://github.com/labsir-un/KIT_Phantom_X_Pincher_ROS2}
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

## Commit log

2025-11-13 se añadieron los objetos de recoleccion
    [EncajeTuboTuerca.0004.ipt, EncajeTuboTuerca.ipt, EncajeTuboTuerca.stl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]
2025-11-19 Se añadieron los modelos de suction gripper, depornto se modifica un poco el gripper con otro tornillo
    [bodySuctionCup.0005.ipt, bodySuctionCup.ipt, bodySuctionCup.stl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]
2025-11-26 se añadieron letreros con numueros para las canastillas
    [unpxp1.0005.ipt, unpxp1.ipt, unpxp1.stl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]
2025-12-03 se añadio el gripper de succion
    [CFFFP_baseCaseRaspberry.3mf, GripperBody v4.0001.ipt, GripperBody v4.ipt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]
2025-12-04 Se actualizo el ensamble del kit completo, ahora tiene el mastil y la canastilla
    [EncajeABaseConTornilloTuboCloset.ipt, EncajeTuboTuerca.0005.ipt, EncajeTuboTuerca.ipt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]
2025-12-10 se añadieron la camara y la ventosa en el kit.iam
    [Glass1.ipt, Glass1.sldprt, MainBody.ipt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]
2025-12-11 se añadieron stls de canastilla y soporte
    [canastilla.0007.ipt, canastilla.0008.ipt, canastilla.ipt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]
2026-07-20 Se añadio el PDF de la monografia y todo el overleaf con el que se hizo el documento, estos archivos estan en documentacion/MONOGRAFIA_KIT
2026-07-21 Se eliminaron archivos que eran innecesarios
    [10.J5¸Ç^ÕûÌåÍâ·¢Ä£ÐÍ.ipt, 10mm standoff v1.ipt, 11.J6Ö÷Ìå^ÕûÌåÍâ·¢Ä£ÐÍ.ipt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]
2026-07-21 Se mejore el readme.md para que se sepa mejor la ubicacion de todos los archivos y se elimaron archivos viejos que correspondian a prototipos
    [Angujo.ipt, EncajeABaseTuboCloset.ipt, EncajeCamaraTubo.ipt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]
